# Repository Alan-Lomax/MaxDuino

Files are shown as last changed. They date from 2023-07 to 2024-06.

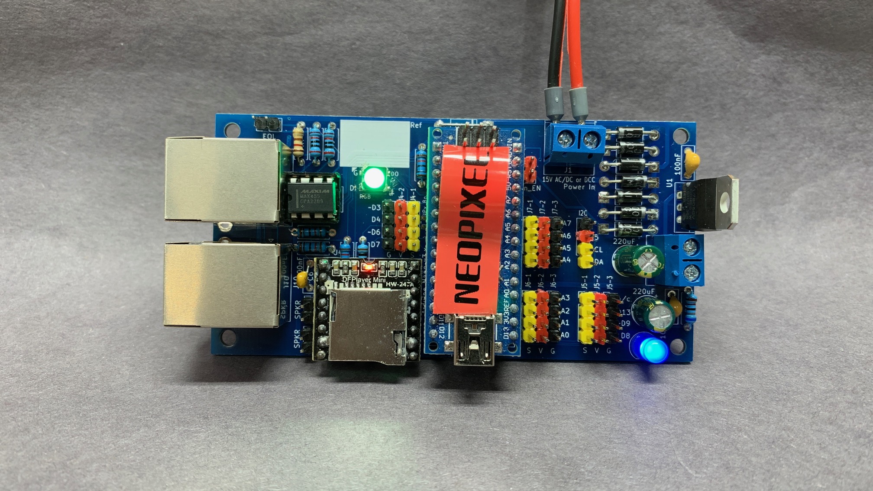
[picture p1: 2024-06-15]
R1.6 (With RJ45)/Images/MaxDuino_R1.5_Under_Test.jpg

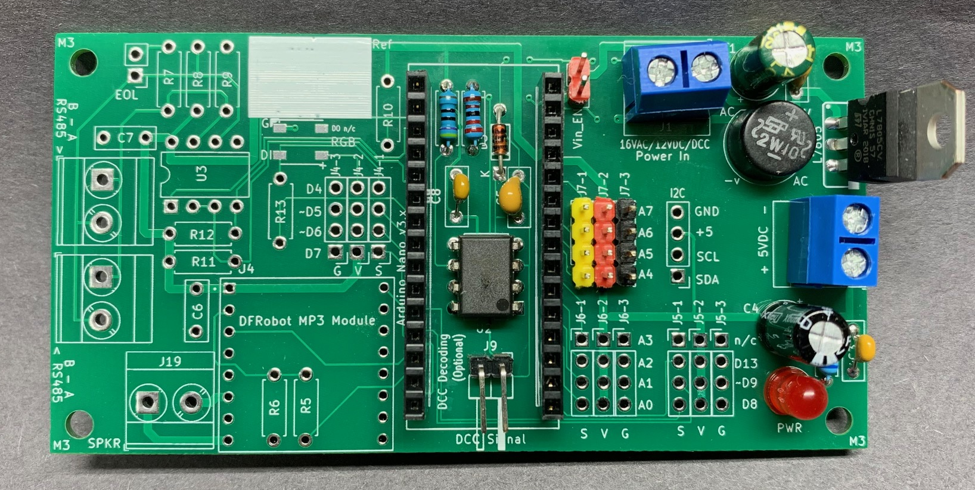
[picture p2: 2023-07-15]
MaxDuino Resources/Construction Photos/07 MaxDuino Header Pins Partially Installed.png

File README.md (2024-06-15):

# MaxDuino
Is a small PCB carrier board that acts as a host for an Arduino NANO.
The PCB provides a multitude of supporting features for the NANO.
It is targeted for use as a model railway animation tool (see feature list)
Because of its flexibility it can be used in many different scenarios.

<B>There are two current versions according to needs:</B>
<Li>R1.6 uses RJ-45 jacks (network patch cords) for power and communications
<Li>R1.4 uses screw terminals for simple wire connections

## Key Features
<Li>Arduino Nano R3 is fully utilized.
<Li>On board NeoPixel for flexible diagnostic use and status reporting.
<Li>Robust on board DC power supply (5V DC, 9-15V DC/AC, or DCC)
<Li>DFRobot MP3 player with SD card and speaker terminals
<Li>Lots of 3 pin headers and an I2C header
<Li>Opto Isolator for decoding DCC packets
<Li>A RJ45 jack is used to connect 12VDC power and RS485 signals between R1.6 boards
<li>Two sets of jacks are provided for easy daisy chaining
<Li>The MAX485 chip has seperate DE/RE pins allowing ICSP of the Arduino. 
<Li>Sample sketches for testing, and to accelerate your own development.
<Li>Detailed build instructions are provided in Excel.

## Status of MaxDuino development 
### Rev 1.6 Is The Latest RJ45 Version 
<Li>No functionality differences vs R1.5.  Minor improvements are: 
<Li>Improved spacing around votage regulator for heatsink mounting
<Li>Added stencilling around 5 volt terminals indicating polarity
<Li>Brought the preamp pins on the Mp3 player out to pads (some people uae external amps)

Since the R1.4 version
<Li>The previous screw terminals for RS485 have been replaced with RJ45 jacks.
<Li>The power supply section received a major redesign.
<li>The round bridge diode is replaced with 4 discrete diodes.
<Li>3 additional diodes are used to drop the input voltage into the L7805 regulator
<Li>A diode has been used to prevent backfeeding power onto the network cable 
(Substitute a jumper where feeding power out is the desired behaviour)
<li>Screw terminals for a speaker are deleted. (Now using 2 pin headers)
<Li>Remote power and RS485 coms tested via a standard network patch cable</Li>
<Li><B>The full test suite has been run and all testing passed successfully.</B>

## Known Issues
<Li>None

### Rev 1.4 Is The Latest Version using screw terminals
<Li>This version is electrically the same as Version 1.3) however the 
<Li>silkscreen errors have been addressed</Li>
<Li><B>All functional testing passed successfully.</B></Li>
<Li>Updated test sketches provided. Test code reflects correct pin assignments,
<Li>Sketches are simplified and compartmentalized as to their the test scope.

### Rev 1.3 and Older Have been removed from GitHub (Files are in the archive)

## MaxDuino KiCad files including GERBERS.
The KiCad files are essentially 'source code' and include:
<Li>the schematic and
<Li>the Printed Circuit Board art work
The Kicad software checks for consistency between these two.

The Gerber files can be thought of as the 'compiled version'. The Gerbers
are seperate files, one for each step in the manufacturing process of a PCB.
The Gerbers are normally saved as a ZIP file and the Zip file is what gets
submitted for manufacture at the fabrication facility of your choice.

# The Panel Version
The MaxDuino PCB is sized 50 mm x 100 mm which means it can easily be panelized
in sets of two. This makes the panelized Maxduino fit on a single 100 mm x 100 mm 
PCB which is the normal 'minimum size' for billing. The short version of this 
is you get twice as many MaxDuinos at no extra cost.

There is a seperate folder containing the Panelized version of the Gerbers.

# Be Aware
Normally all EDITS should be done to the 'single PCB' and then it be repanelized
To repanelize you start a new Kicad project (one with no contents)
and run a 'plug in' to panelize things. You will specfiy which other 
file has the PCB layout you want to panelize. You also set the number of
rows (2) and collumns (1)
The only manual step needed is to add a horizontal line on the edge cut layer.
This will be a 'Vee-Cut' and allows separating the two PCBs easily.

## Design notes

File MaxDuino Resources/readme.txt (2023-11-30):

These are notes and generally useful stuff relevant to the MaxDuino
This material is not essential in order to just build or use the MaxDuino

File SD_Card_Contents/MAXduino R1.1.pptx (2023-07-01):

## MAXduino R1.1

## MaxDuino Block Diagram

DC In (9-15VDC)

AC In (9-16VAC)

DCC In (9-16VAC)

Power Supply

Filtered DC

Regulated 5 VDC

5 VDC

Arduino NANO

5 VDC in or out

Vin_En

Speaker Terminals

MP3 Module

Two Sets
Terminals

RS-485

EOL_En

I2C Header

5 VDC

D10
D11
D12

Vin

D3

5 VDC

5 VDC

D0
D1
D2

A4
A5

D4

DCC Opto-Isolator

5 VDC

DCC Injection

5 VDC

NeoPixel

5 VDC

I/O Header Pins

D4, D5, D6, D7
D8, D9, D13
A0,A1,A2,A3
A4,A5,A6,A7

Only Aref and Reset pins are not used

## MAXduino R1.1

WS2812B
RGB Neopixel

Opto-Isolated DCC Decoding
Under Arduino Nano

16 VAC input or 12 VDC input or
DCC Input

RS485 and Terminals

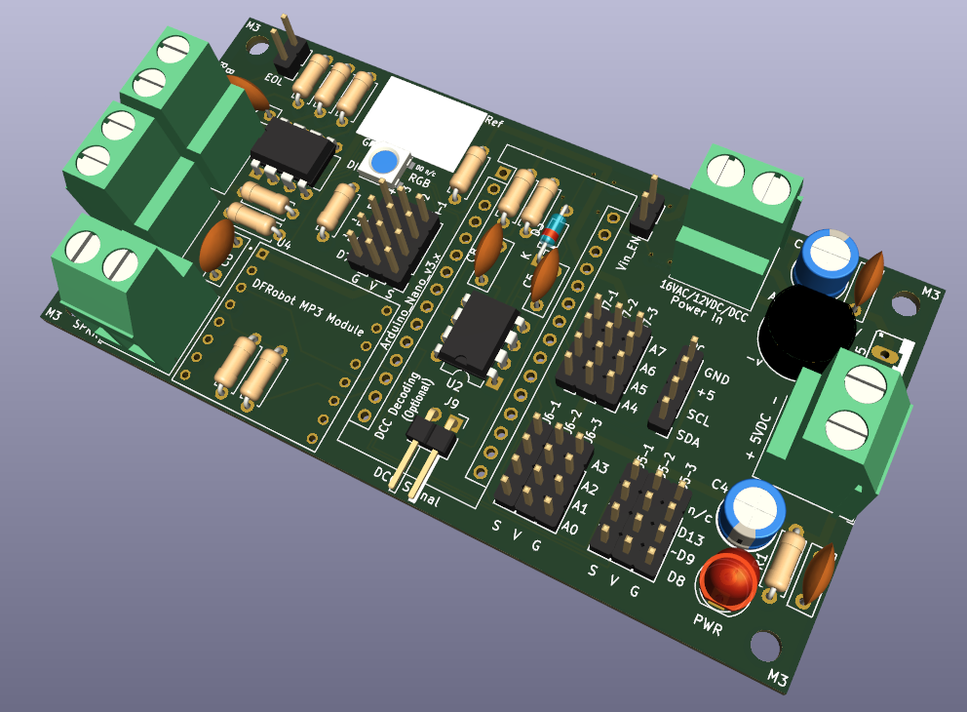
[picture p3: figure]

Versatile Power Supply

I2C

5 VDC input (or output)

Speaker Terminals

MP3 Player

I/O 3 pin headers in groups of 4

Power LED

## Design Review - Power Supply

Power comes in from the left. Up to 16VAC, 12VDC, or a DCC feed. It then goes through full wave bridge rectifier D1 and filter capacitors C1 and C2. This filtered DC voltage is now the input to the 5 volt regulator chip L7805.
The 5 volt regulator is capable of providing 1.5 amps and is internally protected against short circuits.
The 5 volt output is filtered with C3 and C4 to produce a rock steady 5 volt supply for significant projects.
A LED is used to indicate the presence of 5 volts (even without any Arduino present.)
On the right hand side is a second set of terminals which can be used as a 5 volt output to supply other circuits, or this can be used as a 5 volt input (in which case the L7805 regulator and everything to the left of it is not required.
On the left hand inputs, if DCC is used as the power source these signals are also routed to the DCC optoisolator circuit. Notes: The same voltage at the input to the voltage regulator chip can be routed to the Vin pin of the Arduino by inserting a jumper at J2. This is effectively puts the Arduinos own 5 volt regulator in parallel with the L7805. (You must verify Vin is 12VDC or less or the Arduinos on board regulator could be damaged).

## Design Review – DCC Decoder

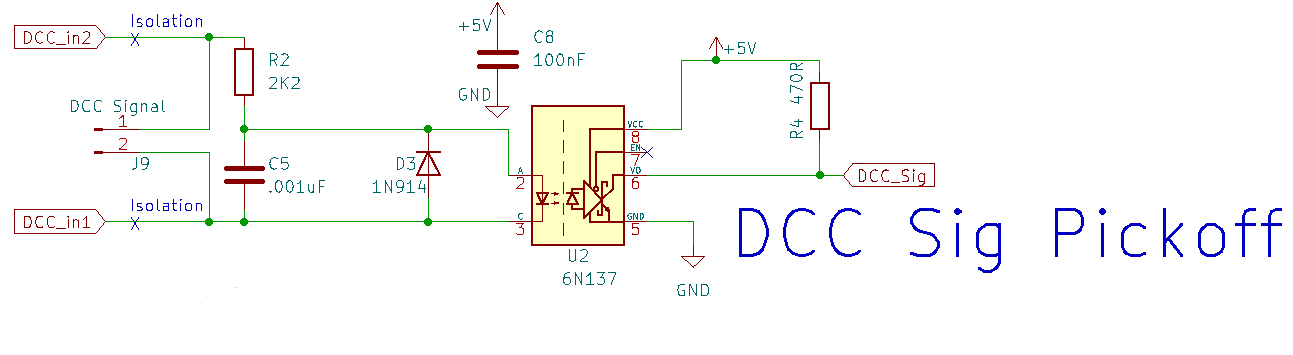
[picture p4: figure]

The DCC signal from the power circuit comes in on the left as DCC_in1 and DCC_in2. These are routed through two isolation points (thin traces on the PCB that can be scratched open circuit if needed). The DCC signal goes onto the 2K2 current limiting resistor R2 and then through the optoisolator U2. D3 provides reverse polarity protection for the optoisolator diode. C5 (in conjunction with R2) provide transient noise rejection. The output of the optoisolator goes to Arduino an pin and is pulled high by R4. Pin 7 is not used (The optoisolator is always enabled)
Note: Those components should be amongst the first installed for access reasons as the Arduino header pins will restrict access after those are installed.
NOTES: If DCC is not used as the MAXduino power supply but you still want to decode dcc signals then the two DCC isolation traces must be made open circuit. These traces are clearly marked on the bottom of the MAXduino PCB.
Once these traces are opened then any power source can be used for the board and an independent DCC signal for decoding can be input via J9 which is a pair of horizontal pins located on the PCB under the Arduino.

## Design Review – MP3 Player

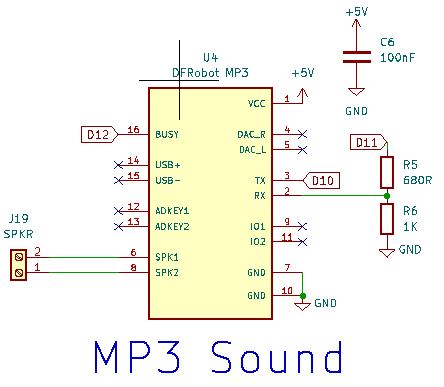
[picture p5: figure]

This circuit utilizes the common DFRobot MP3 player module. This module has an SD card reader and so it can play MP3’s located on a memory card. These can be sound effects, station announcements, or any other sounds as required.
Any small 8ohm speaker can be connected to the speaker terminals. To avoid speaker damage the speaker should be rated at 3 watts or more.
The Tx pin from the module connects to D10 on the Arduino while the Rx pin is connected to D11. The use of software serial is required to implement this but as the transmission speed is a relatively slow 9600 bps this is not an issue. A pair of resistors are used to lower the voltage received by this module as it can glitch if the receive voltage is even slightly over its 5 volt limit.

The busy pin is taken back to the Arduino on pin D12 to provide real time status information.
The following library has been tested #include <DFPlayerMini_Fast.h>
Note: The DFRobot MP3 player module is recommended. There is a similar module with part number MP3-TF-16P but it did not work well for me. Specifically It did not respond to some commands. (e.g.: setting volume)

## Design Review – RS-485 Communications

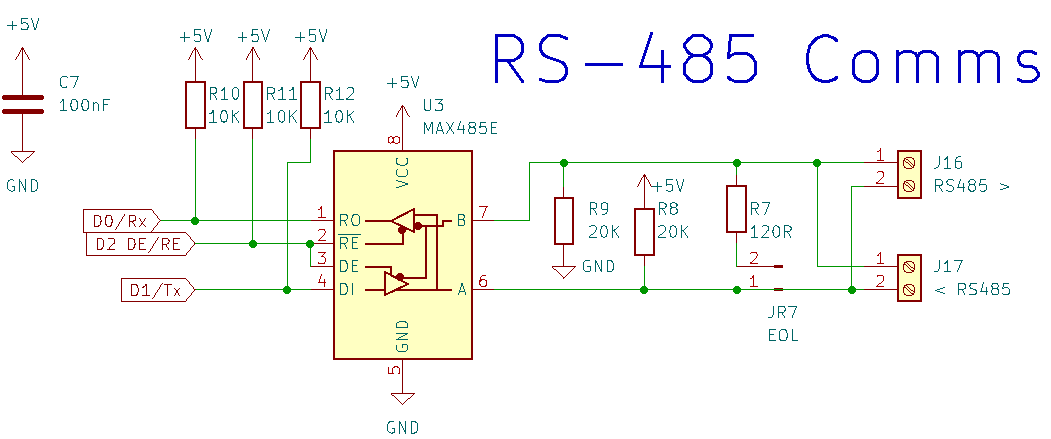
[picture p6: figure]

This circuit utilizes the common MAX485 chip to receive RS485 communications coming in from the right and convert them into standard logic level signals that the Arduino can read. There are two sets of terminals in parallel for the RS485 signals since this module is typically one ‘drop’ and the RS485 signals will daisy chain on. R7 is an EOL (End of Line) termination resistor. The jumper at JR7 should only be installed on one of the MAXduino boards and preferably the one farthest from the sending device (Typically a USB/RS485 interface). This chip interfaces with the Arduino Tx/Rx pins to take advantage of the Arduino UART. D2 sets the direction of transmission since RS485 is only half duplex (cannot transmit and receive at the same time).
The following libraries were used in testing
#include <Auto485.h>

#include <CMRI.h>

## Design Review – RGB

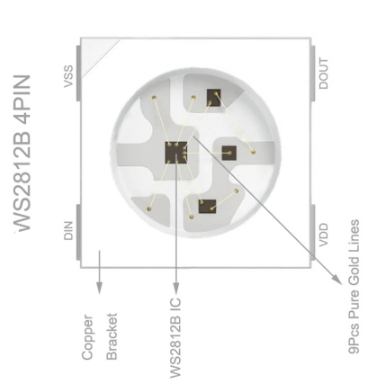
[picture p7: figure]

Pinout for WS2812B NeoPixel chip.
Note Vss = Ground. VDD = + 5 volts
The shown orientation matches the PCB

GND

DO (not used)

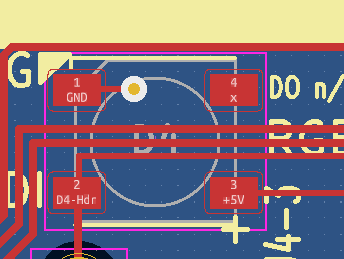
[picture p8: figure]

DI

+5 Volts

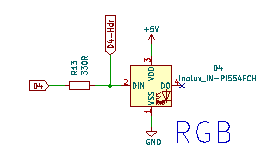
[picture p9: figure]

This small circuit utilizes the common addressable LED WS2812B NeoPixel chip to provide a wide range of colour feedback options. The circuit utilizes one Arduino pin (D4) and has an on board 330 ohm (alternate=470) series resistor for the input pin. The three pin header with D4 is also available and suitable for longer strings of NeoPixel addressable LED’s. Be sure to consider power requirements when using long (more than 30 elements) strings of NeoPixels. Note the PCB stencil has been improved to include chip placement details.
The following library was used in testing
#include <FastLED.h>

## Design Review – Header Pins

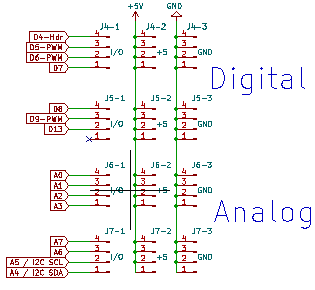
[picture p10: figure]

The I/O pins are arranged as four groups of four.
On the PCB this enables colour coded pins in strips of 4 to be used.
Each of the 15 I/O pins (one is not used) is presented as a 3 pin header.
The pin order is Signal, +5V, Ground … or S V G for short.
This pin order is a common but not universal (so always check your modules)
On the PCB some pins are marked with a tilde ( ~ ).
This is indicating these pins are PWM enabled.
Note A4/A5 pins are also part of the I2C header.

The I2C header provides +5, Ground, SCL and SDA
In the same order as commonly found on OLED displays. Be sure to check the pin order for each device when using I2C. You may of course elect to install these as colour coded pins.

## Design Review – Arduino

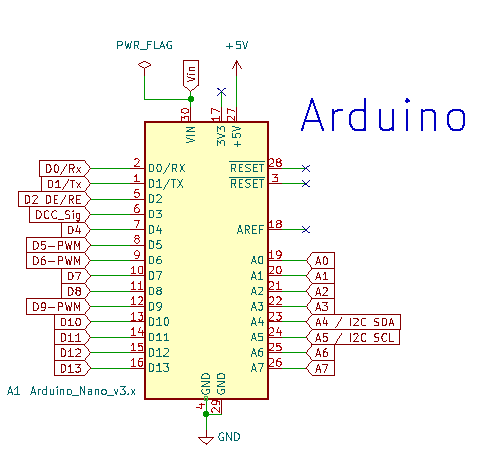
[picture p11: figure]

The Arduino NANO module is almost fully utilized as shown. Only 4 pins have no connections to them.
It is recommended to install female header pins on the PCB so that the NANO module can be simply plugged into those header pins. This also provides ample clearance for the DCC decoder circuit which is located under the Arduino.

## Design Review Full Schematic

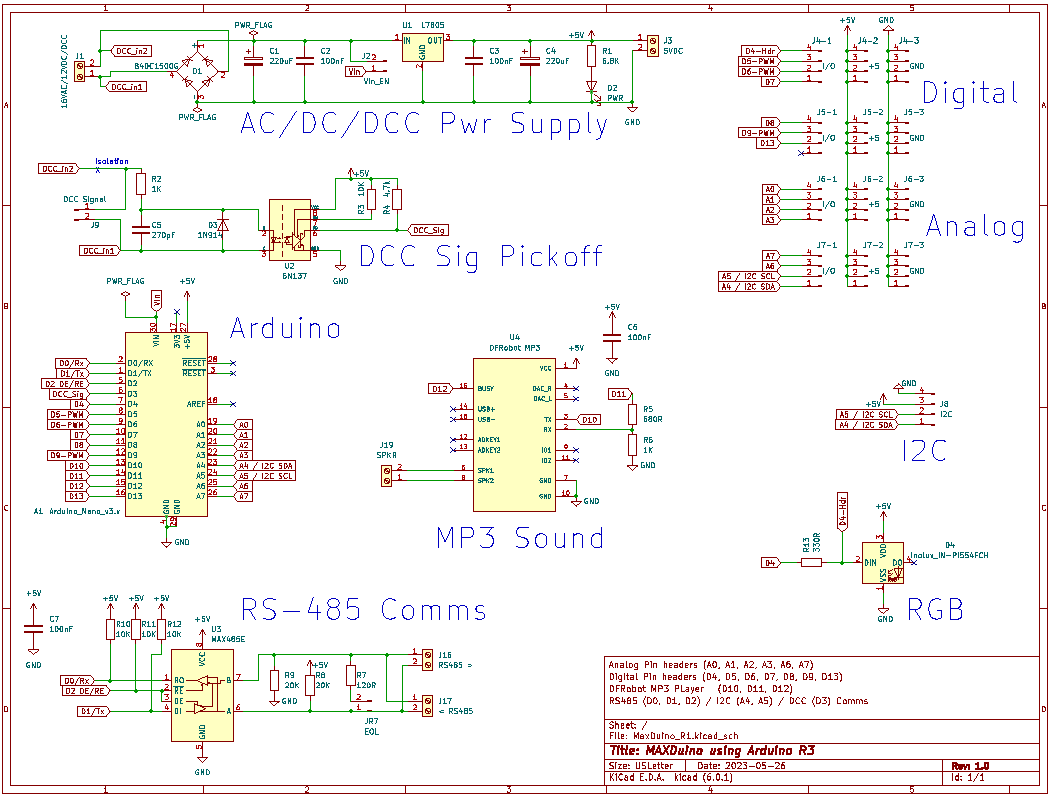
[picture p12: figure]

## Design Review Full PCB

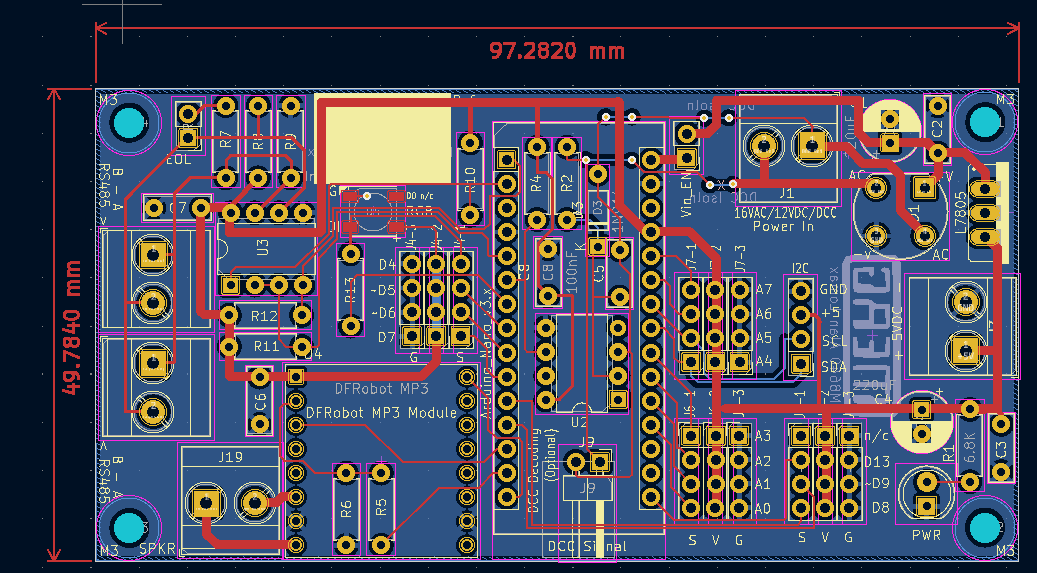
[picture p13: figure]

## Management of Change

Rev 0 – Dec 2022 first 10 prototypes ordered. Built up and tested.
Rev 1 – May 29 2023 second batch of 10 prototypes ordered. Fixed DCC decoding, added 5 volt power input, added NeoPixel, changed 3 pin header and I2C header arrangement, Larger power traces, clarified stenciling. Rev 1 arrived June 12 2023: 3 of 5 boards (they contacted me about 2 that failed manufacturing) – credit note is on file but 3 is enough for testing.
One PCB (Two MaxDuino) were given to Ian for evaluation.
Rev 1.1 Revised DCC Decoder circuit. Additional stencil near RGB NeoPixel to aid with orientation, additional stencil for double isolation of DCC signal pickoff from power supply section.
Ordered 5 PCB’s June 29 2023 from JLCPCB.

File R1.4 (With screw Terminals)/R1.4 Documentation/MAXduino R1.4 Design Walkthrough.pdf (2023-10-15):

# MaxDuino R1.4 Design Walkthrough

Note: In some cases photos of a previous revision are used where there is no material difference to the main message.

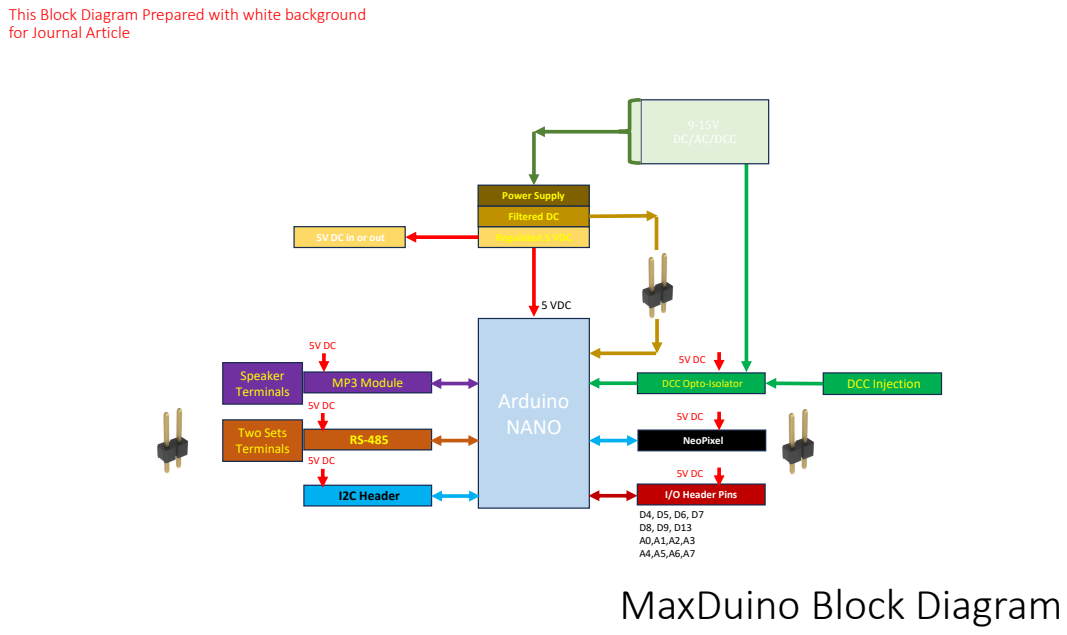
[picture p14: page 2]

This Block Diagram Prepared with white background
for Journal Article

5V DC in or out

# MaxDuino PCB

## (General arrangement)

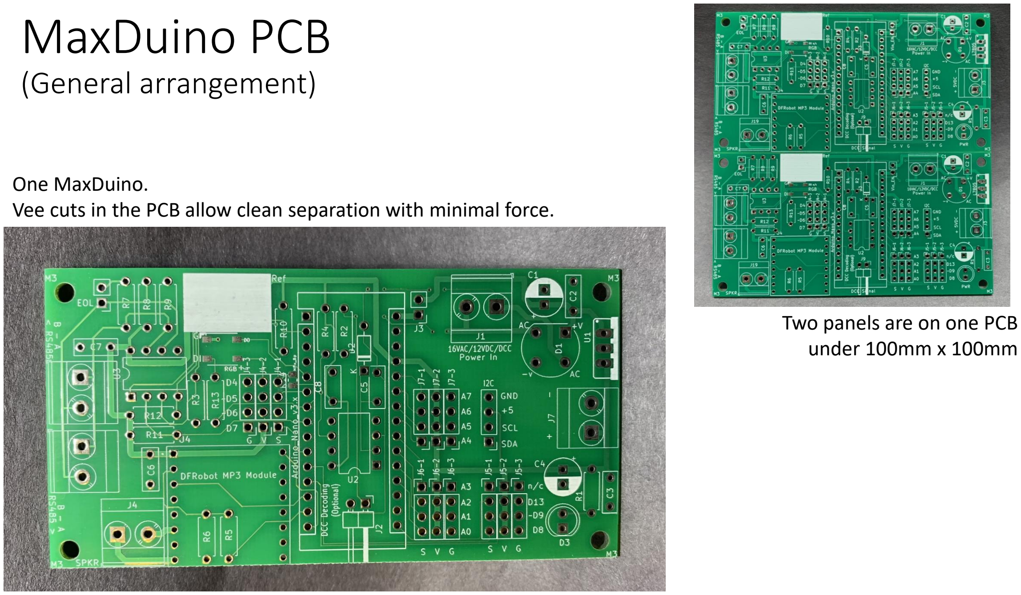
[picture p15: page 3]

Two panels are on one PCB
under 100mm x 100mm

One MaxDuino.
Vee cuts in the PCB allow clean separation with minimal force.

# MaxDuino 1.x

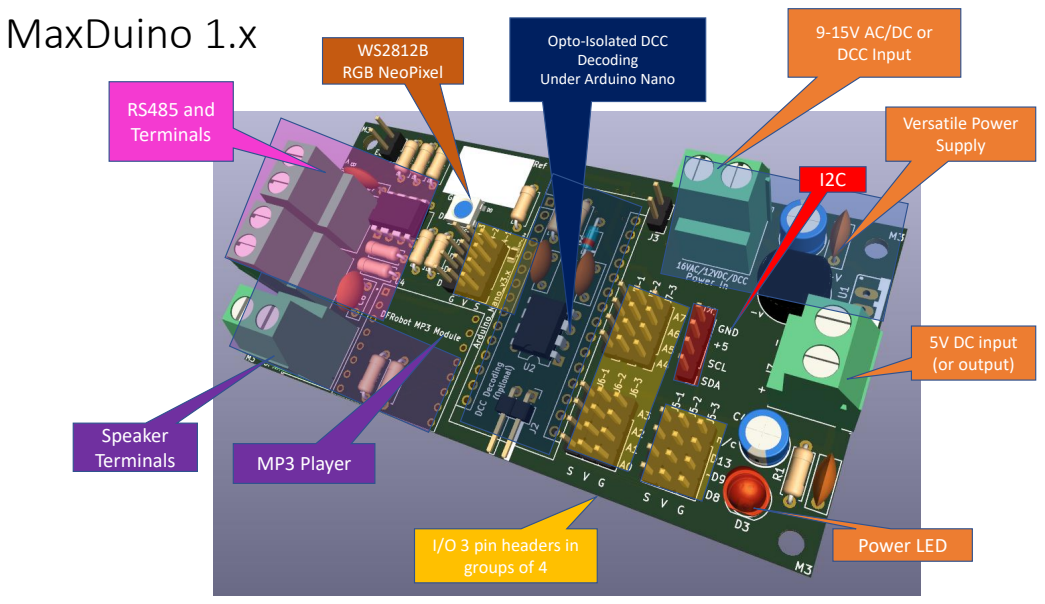
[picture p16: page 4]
Versatile Power Supply; 5V DC input (or output); MP3 Player; RS485 and Terminals; Power LED; WS2812B RGB NeoPixel; Speaker Terminals

DCC Input

Opto-Isolated DCC
Decoding
Under Arduino Nano

I/O 3 pin headers in
groups of 4

# Design Review - Power Supply

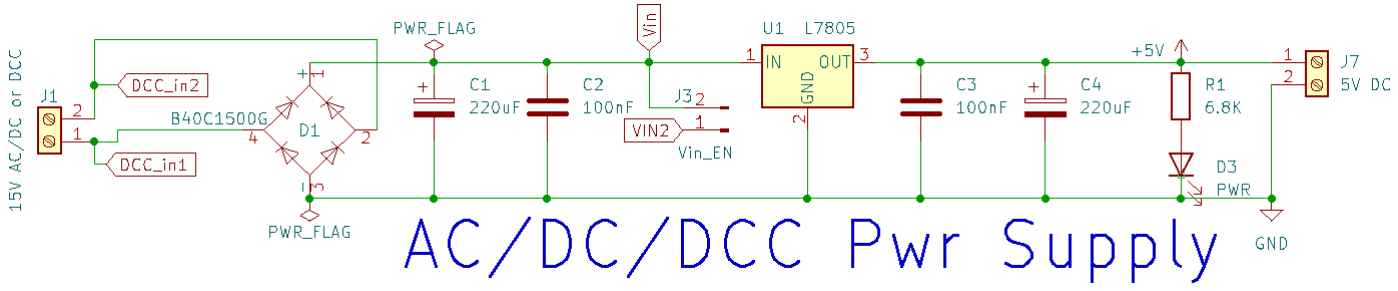
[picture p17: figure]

Power comes in from the left. Up to 9-15V AC/DC, or a DCC feed. It then goes through full wave bridge rectifier D1 and filter capacitors C1 and C2. This filtered DC voltage is now the input to the 5 volt regulator chip L7805.
The 5 volt regulator is capable of providing 1.5 amps and is internally protected against thermal overloads and short circuits. The 5 volt output is filtered with C3 and C4 to produce a steady 5 volt supply for significant projects. These capacitors are also needed to ensure stability of the voltage regulator. A LED is used to indicate the presence of 5 volts (even without any Arduino present.) On the right hand side is a second set of terminals which can be used as a 5 volt output to supply other circuits, or this can be used as a 5 volt input (in which case the L7805 regulator and everything to the left of it is not required.
Notes: If DCC is used as a power source the use of a heat sink on the L7805 is strongly recommended. Also if DCC is used as the power source that signal is also routed to the DCC optoisolator circuit.
The input to the voltage regulator chip Vin can be routed to the Vin pin of the Arduino by inserting a jumper at Vin_En. This puts the Arduinos own 5 volt regulator in parallel with the L7805. (You must verify Vin is 12VDC or less else the Arduinos on board regulator could be damaged).

# Design Review – DCC Decoder

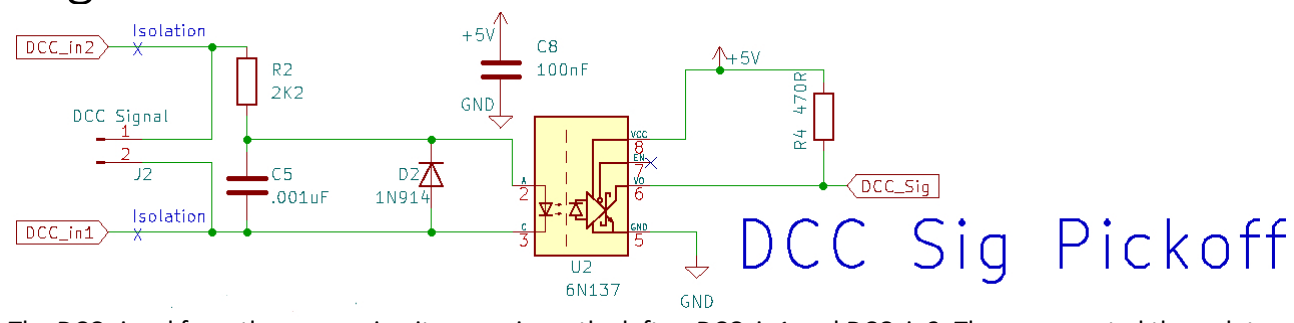
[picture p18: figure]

The DCC signal from the power circuit comes in on the left as DCC_in1 and DCC_in2. These are routed through two isolation points which are thin traces and are clearly marked on the bottom of the MaxDuino PCB.
The DCC signal goes onto the 2K2 current limiting resistor R2 and then through the optoisolator U2. D2 provides reverse polarity protection for the optoisolator diode. C5 (in conjunction with R2) provide transient noise rejection. Pin 7 is not used as the optoisolator has an internal pulllup. The output of the optoisolator goes to Arduino an pin and is pulled high by R4. Note the DCC input goes to Arduino Pin D3. This is very important because this is only one of two pins on the Nano that can have interrupts attached which is important for time critical decoding.

NOTES: If DCC is not used as the MaxDuino power supply but you still want to decode dcc signals then the two DCC isolation traces must be made open circuit. Once these traces are opened then the MaxDuino power source and the DCC decoding are isolated from each other. An independent DCC signal for decoding can be input via J2 which is a pair of horizontal pins located on the PCB under the Arduino.

# Design Review – MP3 Player

This circuit utilizes the common DFRobot MP3 player module. This module has an SD card reader and so it can play MP3’s located on a memory card. These can be sound effects, station announcements, or any other sounds as required.
Any small 8ohm speaker can be connected to the speaker terminals. To avoid speaker damage the speaker should be rated at 3 watts or more.

The Tx pin from this module connects to D10 on the Arduino while the Rx pin is connected to D11. The use of software serial is required to implement this but as the transmission speed is a relatively slow 9600 bps this is not an issue. A pair of resistors are used to lower the voltage received by this module as it can glitch if the Rx voltage is even slightly over its 5 volt limit.
(Alternate design – omit R6, use 1K resistor for R5)

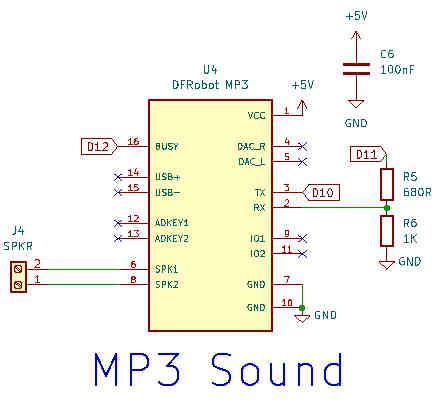
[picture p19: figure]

The busy pin is taken back to the Arduino on pin D12 to provide real time status information.
It is possible to ‘ask’ the module for its status via software also. Both approaches have been tested and work as expected. The following library has been tested #include <DFPlayerMini_Fast.h>

Note: The DFRobot MP3 player module is recommended. There is a similar module with part number MP3-TF-16P but it did not work well for me. Specifically It did not respond to some serial commands. (e.g.: setting volume)

# Design Review

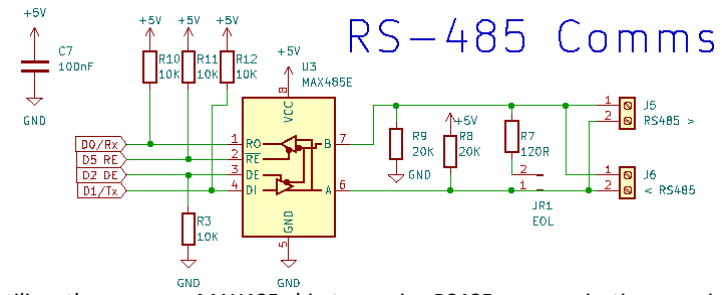
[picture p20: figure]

This circuit utilizes the common MAX485 chip to receive RS485 communications coming in from the right and convert them into standard logic level signals that the Arduino can read. There are two sets of terminals in parallel for the RS485 signals since this module is typically just one ‘drop’ and the RS485 signals will daisy chain onward. R7 is an EOL (End of Line) termination resistor. The EOL jumper at R7 should only be installed on one of the MaxDuino boards and preferably the one farthest from the sending device (Typically a USB/RS485 interface). This chip interfaces with the Arduino Tx/Rx pins to take advantage of the Arduino UART. As of R1.3 both D2 and D5 set the direction of transmission. The use of pull up and pull down resistors on these means that in circuit serial programming can work without disrupting other RS485 communications on the wires. (In the instance of a large network for example).
The following libraries were used in testing
#include <Auto485.h>

#include <CMRI.h>

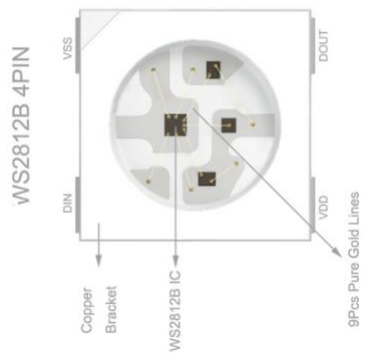
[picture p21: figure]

# Design Review – NeoPixel

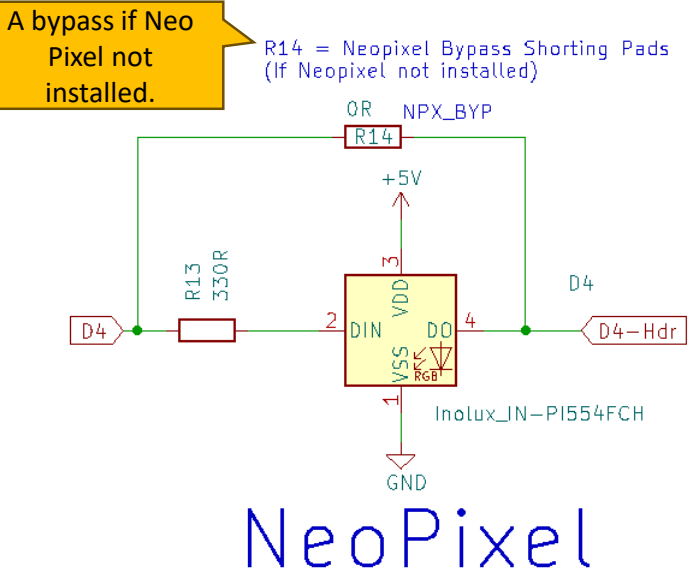
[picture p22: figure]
A bypass if Neo Pixel not installed.
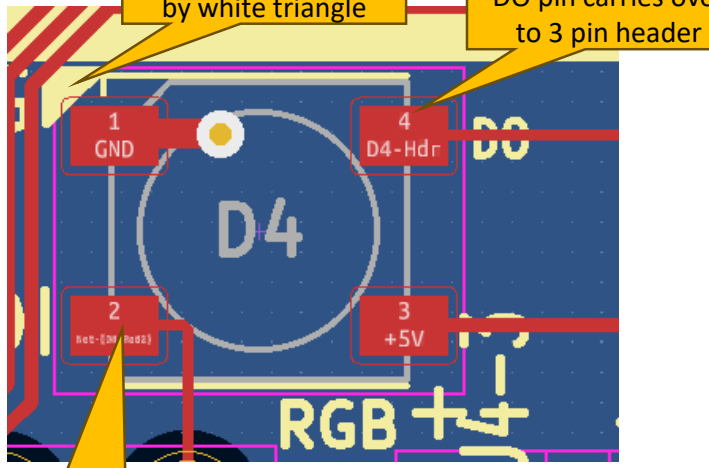
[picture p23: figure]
to 3 pin header

This small circuit utilizes the common addressable LED WS2812B NeoPixel chip to provide a wide range of colour feedback options. The circuit utilizes one Arduino pin (D4) and has an on board 330 ohm series resistor for the input pin. The three pin header with D4 is also available and suitable for longer strings of NeoPixel addressable LED’s. Be sure to consider power requirements when using long (more than 10 elements) strings of NeoPixels. Note a bypass set of pads exist (R14 is specified as a SMD component nut is not normally installed – only the solder pads are used and can shorted if the NeoPixel is not installed. Doing so connects D4 directly to the header pin bypassing the onboard Neo Pixel. If the header pin D4 is used for additional NeoPixels the onboard NeoPixel is index 0, and the external NeoPixels start at index 1. The following library was used in testing #include <FastLED.h>.

Pinout for WS2812B NeoPixel chip. Note Vss = Ground. VDD = + 5V
The orientation shown matches the PCB

Ground pin denoted
by white triangle | DO pin carries over

DI pin from NANO
pin D4 via 330R

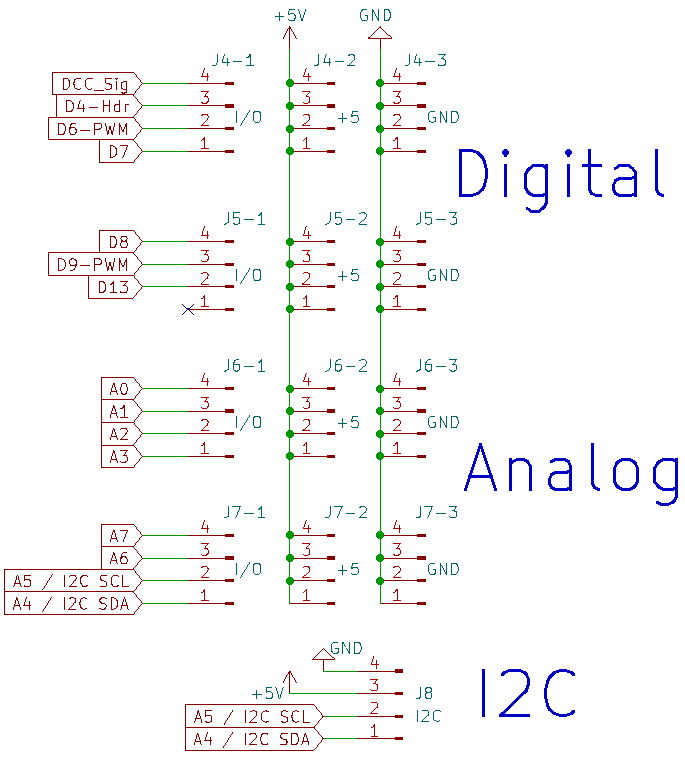
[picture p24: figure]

# Design Review – Header Pins

The I/O pins are arranged as four groups of four. Spaced to enables colour coded pins in strips of 4. Each of the I/O pins is presented as a 3 pin header. The pin order is Signal, +5V, Ground or S V G for short. This pin order is a common but not universal (so always check your modules)

On the PCB some pins are marked with a tilde ( ~ ). This is indicating these pins are PWM enabled.

Notes: There are subtle differences in the arrangement of the header pins between PCB version 1.3 and 1.4 Version 1.4 is shown.

The DCC decoder circuit ties into pin D3. It has a strong (470 ohm) pullup located on the PCB. Pin D4 is normally the output of the on-board NeoPixel. A4/A5 pins are also part of the I2C header. The I2C header provides +5, Ground, SCL and SDA (In the same order as commonly found on OLED displays.) Be sure to check your pin order when using I2C.

# Design Review – Arduino

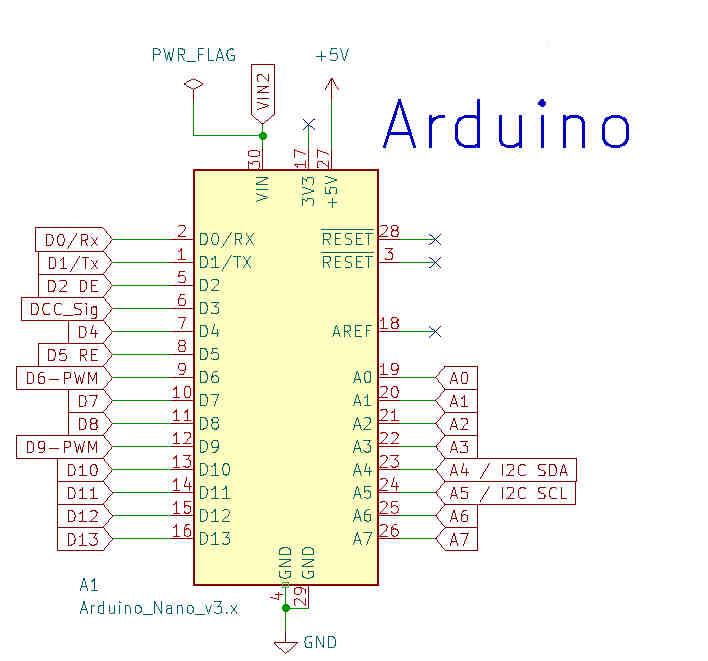
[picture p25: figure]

The Arduino NANO module is almost fully utilized as shown. Only 4 pins have no connections to them.

As of R1.3 both D2 and D5 are used for RS485 direction control.

It is recommended to install female header pins on the PCB so that the NANO module can be simply plugged into those header pins. This also provides ample clearance for the DCC decoder circuit located under the Arduino.

# Design Review Full Schematic

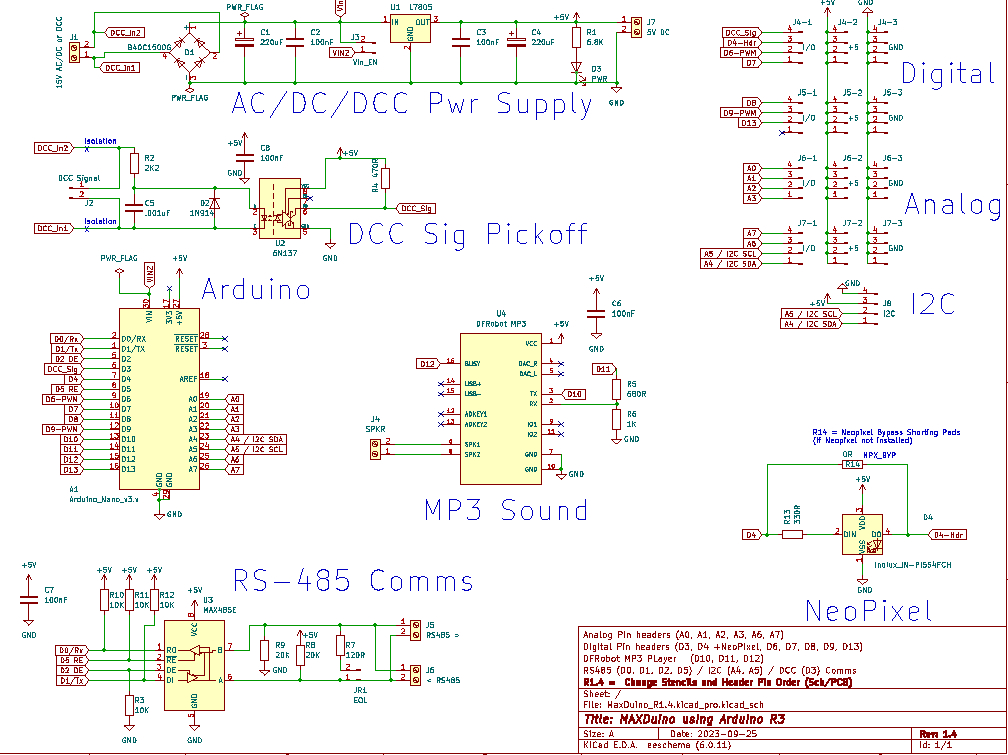
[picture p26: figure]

# Design Review Full PCB


# Management of Change

Rev 0 – Dec 2022 first 5 PCB’s (enough for 10 prototypes) ordered. Platform for developing test code.

Rev 1 – May 29 2023 second batch of 5 PCB’s ordered. Tried fixing DCC decoding, added 5 volt power input, added NeoPixel, changed 3 pin header and I2C header arrangement, Larger power traces, clarified stenciling. Found flaw in DCC Decoder section. One PCB (Two MaxDuino) were given to Ian for evaluation.

Rev 1.1 Revised DCC Decoder circuit. Additional stencil near RGB NeoPixel to aid with orientation, additional stencil for double isolation of DCC signal pickoff from power supply section.
Ordered two batches of 5 PCB’s June 29 2023 from JLCPCB. All testing passed.

Rev 1.2 Revised RS485 circuit to use 2 pins for enabling direction control. This puts both into high impedance state when doing ICSP. Also added flow through for the on board NeoPixel and ability to bypass the NeoPixel if not needed.

Rev 1.3 Previous revision changed the pin for DCC decoding – to one that does not support interrupts. This version moves DCC decoding back to pin D3 while retaining 2 pin direction control on RS485. All testing passed on October 14 2023.

Rev 1.4 During final prep of MERG article editor suggested minor changes that in turn suggested minor fixes to front and back stenciling. Circuit was electrically unchanged from version 1.3

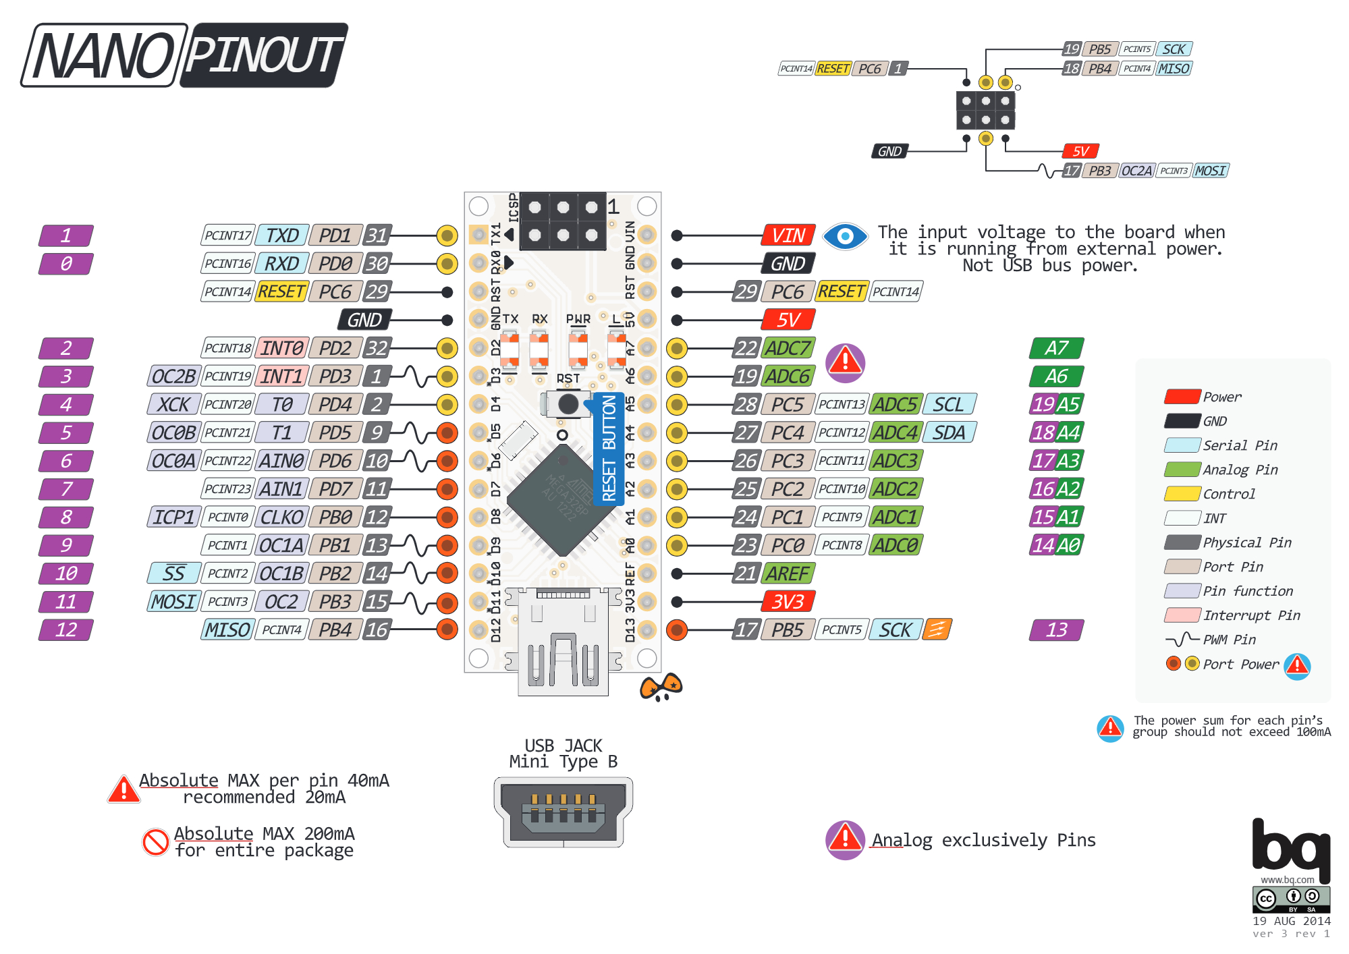
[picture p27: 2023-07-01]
MaxDuino Resources/DataSheets/NANO_PINOUT.jpg

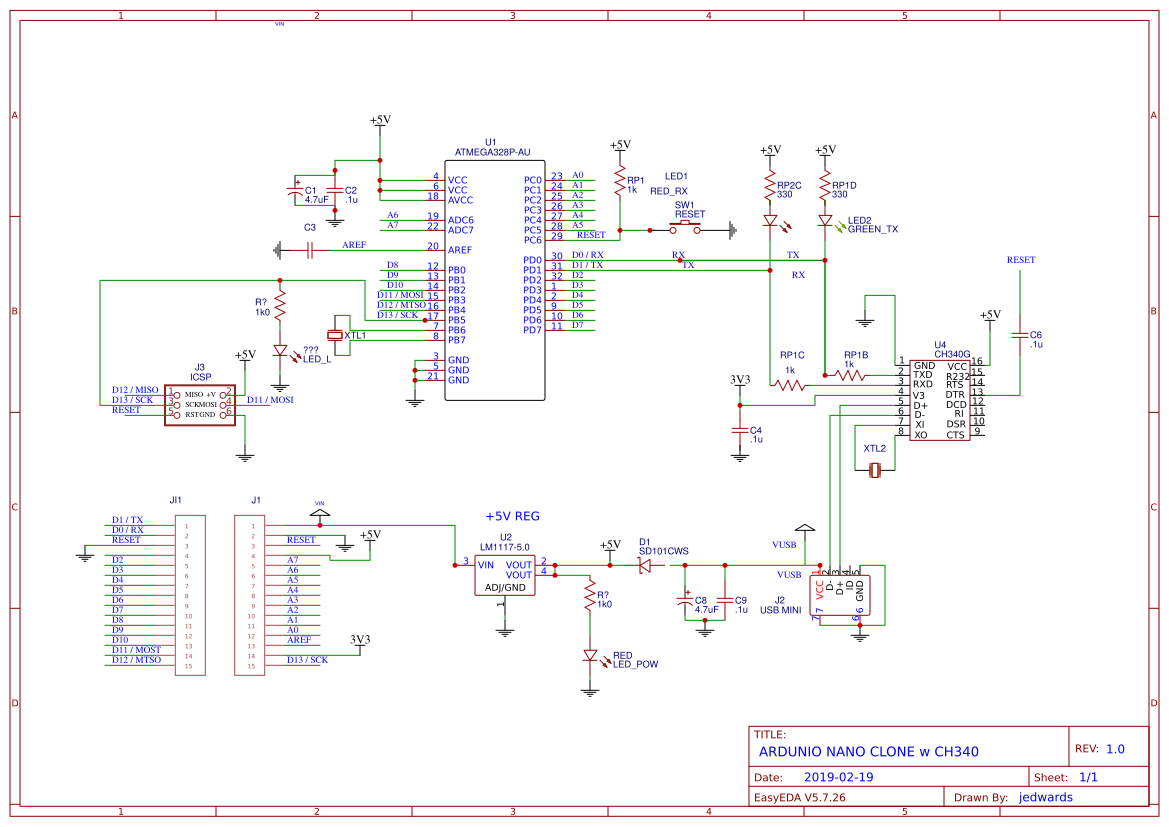
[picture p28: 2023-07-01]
MaxDuino Resources/DataSheets/Nano Schematic.png

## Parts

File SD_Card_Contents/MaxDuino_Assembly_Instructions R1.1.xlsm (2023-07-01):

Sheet: Instructions
 | MaxDuino Assembly Instructions R1.1
 | Known Issues | None. This document is draft and will be updated as needed.
Step | Action | Comments
 |  | With the MaxDuiono PCB there is some flexibility in which functions you wish to implement, and therefore what parts you need to include or not. (for example you may not wish to include the MP3 player module). To facilitate this a tab in this workbook is a configuration sheet that allows you to pick the features you want a given PCB to have. This then produces a consolidated parts list for just those features. The assembly instructions are broken down into sections (on the brown tabs below) according to the functions. So .. start with these 3 instructions:
1 | Make Choices | On the features tab chose the features you want on up to 5 different MaxDuino modules
2 | Review consolidated BOM | The consolidated BOM lists the parts you need to implement the features you have selected. There is a column where you can put your parts on hand I have included links for many of them. Note that in many cases you are buying in bulk (say 10 pieces where you may only need 2). Generally this is still more economical. Pricing is highly variable and was current as of June 2023. Shipping reflects my location (Canada) .. yours will of course be different.
3 | Wait for Parts | Organize your parts and workspace. You will need a soldering iron (pencil type preferred) and some acid free electronics solder. A small bead of 'bluetack' putty is very helpful but not strictly required. (to hold the components in place when you flip the circuit board over to solder that first lead in place.)
 | General advice | Before soldering use the Printed Circuit Board (PCB) as a guide and bend diode and resistor leads 90 degrees so they match the hole spacing on the PCB. In general it is a best practice is to start with the smaller parts closest to the surface of the PCB and work on up to the taller / larger parts. Solder only one component onto the board at a time AND also solder only one lead of that component. Flip the PCB over and verify proper orientation and fit to the board before resuming soldering the remaining leads and moving onto the next component. As parts are soldered into place the excess leads can be trimmed off the bottom using small cutters.

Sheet: Features
Home
 |  | Module #1 | Module #2 | Module #3 | Module #4 | Module #5
 | Arduino | 1 | 0 | 0 | 0 | 0 | Required per module
 | Flexible Power Supply | 1 | 0 | 0 | 0 | 0
 | 5 Volt Input Power Supply | 1 | 0 | 0 | 0 | 0
 | DCC Decoder | 1 | 0 | 0 | 0 | 0
 | MP3 Player | 1 | 0 | 0 | 0 | 0
 | RS485 communications | 1 | 0 | 0 | 0 | 0
 | I/O Headers | 1 | 0 | 0 | 0 | 0
 | I2C Headers | 1 | 0 | 0 | 0 | 0
 | RGB Neopixel | 1 | 0 | 0 | 0 | 0
Instructions:
1 | For each module indicate features you want the module to have by clicking the appropriate cell.
2 | Refer to Consolidated BOM for your parts / shopping list
Notes: | A flexible power supply requires 5 volt power supply parts also. (The 5 volt supply can work without the flexible supply)
 | A MaxDuino PCB is Implied per Module of course!
 | For current hardware test status see tab:
 | PCB R1 Testing

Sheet: Consolidated BOM
References | Value | Needed Count | On Hand | To Get | Supplier | Description | Link | Multiplier | Qty | Unit Price | Shipping | Extended Price (Needed Parts Only) | Extended Price (All Parts)
A1 | Arduino_Nano_v3.x (Check MaxDuino PCB also) | 1 | 0 | 1 | AliExpress | Atmega328P with Mini USB (Needs Soldering) | Link (https://www.aliexpress.com/item/1005002966043359.html) | 1 | 1 | $2.93 | $1.42 | $4.35 | $4.35
 | Female Header Pins for Arduino | 1 | 0 | 1 | AliExpress | 10 pieces 1x40 female header pin | Link (https://www.aliexpress.com/item/1005002577212594.html?curPageLogUid=OAFMO7EpaR5l) | 0.1 | 1 | $2.45 | $2.00 | $0.45 | $0.45
 | Female Header Pins for MP3 module | 1 | 0 | 1 | AliExpress | 10 pieces 1x40 female header pin | Link (https://www.aliexpress.com/item/1005002577212594.html?curPageLogUid=OAFMO7EpaR5l) | 0.1 | 1 | $2.45 | $2.00 | $0.45 | $0.45
C1,C4 | 220uF 25VDC | 2 | 0 | 2 | AliExpress | 20 pieces Electrolytic Capacitor | Link (https://www.aliexpress.com/item/1005004304037018.html?curPageLogUid=8TY8WNbrsxtg) | 0.05 | 2 | $1.03 | $2.53 | $0.36 | $0.36
C2, C3, C6, C7, C8 | 100nF (0.1uF) commonly marked as 104 | 5 | 0 | 5 | AliExpress | Qty 100 50V Ceramic | Link (https://www.aliexpress.com/item/1005002290441861.html) | 0.01 | 5 | $1.19 | $1.72 | $0.15 | $0.15
C5 | .001uF commonly marked as 102 | 1 | 0 | 1 | AliExpress | Qty 100 50V Ceramic | Link (https://www.aliexpress.com/item/1005002290441861.html) | 0.01 | 1 | $1.19 | $1.72 | $0.03 | $0.03
D1 | B40C1500G | 1 | 0 | 1 | AliExpress | 10 pack of 2 AMP Bridge Rectifier | Link (https://www.aliexpress.com/item/32861907980.html) | 0.1 | 1 | $1.73 | $1.61 | $0.33 | $0.33
D2 | PWR LED | 1 | 0 | 1 | AliExpress | Assorted LEDs | Link (https://www.aliexpress.com/item/1005003480981131.html) | 0.01 | 1 | $5.49 | $0.29 | $0.06 | $0.06
D3 | 1N914 | 1 | 0 | 1 | AliExpress | Qty 100 Fast Acting Signal Diode | Link (https://www.aliexpress.com/item/1005003345825307.html?curPageLogUid=WmEe9ymi5x88) | 0.01 | 1 | $1.52 | $1.56 | $0.03 | $0.03
D4 | Inolux_IN-PI554FCH | 1 | 0 | 1 | AliExpress | WS2812B Neopixel (White surface mount) | Link (https://www.aliexpress.com/item/4001345875756.html) | 0.1 | 1 | $1.24 | $0.00 | $0.12 | $0.12
J1, J3, J16, J17, J19 | Screw Terminals | 5 | 0 | 5 | AliExpress | 20 pack of Small screw Terminals for PCB | Link (https://www.aliexpress.com/item/1005004039299571.html) | 0.05 | 5 | $1.68 | $1.91 | $0.90 | $0.90
J2, JR7 | 2 pin male header | 2 | 0 | 2 | AliExpress | 10 pieces 40 pin header | Link (https://www.aliexpress.com/item/1005003016826921.html) | 0.005 | 2 | $0.86 | $1.43 | $0.02 | $0.02
J4-1, J5-1, J6-1, J7-1, J8 | 4 pin header Yellow | 5 | 0 | 5 | AliExpress | 10 pieces 40 pin header | Link (https://www.aliexpress.com/item/1005003016826921.html) | 0.01 | 5 | $0.86 | $1.43 | $0.11 | $0.11
J4-2, J5-2, J6-2, J7-2 | 4 pin header Red | 4 | 0 | 4 | AliExpress | 10 pieces 40 pin header | Link (https://www.aliexpress.com/item/1005003016826921.html) | 0.01 | 4 | $0.86 | $1.43 | $0.09 | $0.09
J4-3, J5-3, J6-3, J7-3 | 4 pin header Black | 4 | 0 | 4 | AliExpress | 10 pieces 40 pin header | Link (https://www.aliexpress.com/item/1005003016826921.html) | 0.01 | 4 | $0.86 | $1.43 | $0.09 | $0.09
J9 | 2 pin right angle male header | 1 | 0 | 1 | AliExpress | 10 pieces 40 pin right angle header | Link (https://www.aliexpress.com/item/4000694229610.html?curPageLogUid=bNZEWRNzBArE) | 0.01 | 1 | $1.23 | $1.61 | $0.03 | $0.03
R7 | 120R | 1 | 0 | 1 | AliExpress | Qty 100 1/4 watt 5% Resistor | Link (https://www.aliexpress.com/item/1005003818444423.html) | 0.01 | 1 | $0.64 | $1.35 | $0.02 | $0.02
R13 | 330R | 1 | 0 | 1 | AliExpress | Qty 100 1/4 watt 5% Resistor | Link (https://www.aliexpress.com/item/1005003818444423.html) | 0.01 | 1 | $0.64 | $1.35 | $0.02 | $0.02
R5 | 680R | 1 | 0 | 1 | AliExpress | Qty 100 1/4 watt 5% Resistor | Link (https://www.aliexpress.com/item/1005003818444423.html) | 0.01 | 1 | $0.64 | $1.35 | $0.02 | $0.02
R2, R6 | 1K | 2 | 0 | 2 | AliExpress | Qty 100 1/4 watt 5% Resistor | Link (https://www.aliexpress.com/item/1005003818444423.html) | 0.01 | 2 | $0.64 | $1.35 | $0.04 | $0.04
R4 | 470R | 1 | 0 | 1 | AliExpress | Qty 100 1/4 watt 5% Resistor | Link (https://www.aliexpress.com/item/1005003818444423.html) | 0.01 | 1 | $0.64 | $1.35 | $0.02 | $0.02
R1 | 6.8K | 1 | 0 | 1 | AliExpress | Qty 100 1/4 watt 5% Resistor | Link (https://www.aliexpress.com/item/1005003818444423.html) | 0.01 | 1 | $0.64 | $1.35 | $0.02 | $0.02
R10, R11, R12 | 10K | 3 | 0 | 3 | AliExpress | Qty 100 1/4 watt 5% Resistor | Link (https://www.aliexpress.com/item/1005003818444423.html) | 0.01 | 3 | $0.64 | $1.35 | $0.06 | $0.06
R8, R9 | 20K | 2 | 0 | 2 | AliExpress | Qty 100 1/4 watt 5% Resistor | Link (https://www.aliexpress.com/item/1005003818444423.html) | 0.01 | 2 | $0.64 | $1.35 | $0.04 | $0.04
U1 | L7805 T0220 | 1 | 0 | 1 | AliExpress | Qty 50 5 Volt Regulator | Link (https://www.aliexpress.com/item/1005005622160274.html?curPageLogUid=Y4rvTNfoPDhb) | 0.02 | 1 | $2.49 | $1.75 | $0.08 | $0.08
HeatSink | Optional T0220 Heatsink for U1 | 1 | 0 | 1 | AliExpress | Qty 10 heat sink with Mounting hardware | Link (https://www.aliexpress.com/item/4000190314199.html?scm_id=1007.40000.326746.0&scm-url=1007.40000.326746.0) | 0.1 | 1 | $1.16 | $2.42 | $0.36 | $0.36
U2 | 6N137 8 pin DIP | 1 | 0 | 1 | AliExpress | OptoIsolator | Link (https://www.aliexpress.com/item/1005002777275459.html?curPageLogUid=xG6J9gDGvLlx) | 0.1 | 1 | $2.24 | $1.56 | $0.38 | $0.38
U3 | MAX485E 8 pin DIP | 1 | 0 | 1 | AliExpress | 10 pack Transceiver Chip | Link (https://www.aliexpress.com/item/1005002848215276.html?curPageLogUid=bMryawO8OFpU) | 0.1 | 1 | $1.42 | $1.56 | $0.30 | $0.30
U4 | DFRobot MP3 | 1 | 0 | 1 | AliExpress | Qty 10 DFRobot MP3 Module | Link (https://www.aliexpress.com/item/1005004522532733.html) | 0.1 | 1 | $11.05 | $6.54 | $1.76 | $1.76
SPKR | 8 ohm 3 watt | 1 | 0 | 1 | AliExpress | 3 watt speaker | Link (https://www.aliexpress.com/item/1005005457205541.html?curPageLogUid=SK1ZYRLQax4i) | 0.5 | 1 | $0.90 | $4.99 | $2.95 | $2.95
SD Card | any capacity under 32 GB | 1 | 0 | 1 | AliExpress | Small Capacity SD Card (32GB MAX) | Link (https://www.amazon.ca/Lerdisk-Wholesale-Capacity-Produced-Authorized/dp/B09VYYZT5G?s=pc) | 1 | 1 | $2.00 | $3.00 | $5.00 | $5.00
PCB | MaxDuino Printed Circuit Board | 1 | 0 | 1 | JLCPCB | Min order is 5 PCBs (2 ccts per) | Link (https://jlcpcb.com/) | 0.1 | 1 | $5.00 | $10.00 | $1.50 | $1.50
 |  |  |  |  |  |  |  |  |  |  | Total | $20.13 | $20.13
 |  |  |  |  |  |  |  |  |  | Extras | Lump Sum | $0.00 | $0.00
 |  |  |  |  |  |  |  |  |  | Extras (as %) | 0% | $0.00 | $0.00
 |  |  |  |  |  |  |  |  |  |  | All in | $20.13 | $20.13

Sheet: BOM
Reference(s) | Value | Flexible Power Supply | 5 Volt Input Power Supply | DCC Decoder | MP3 Player | RS485 communications | I/O Headers | I2C Headers | RGB Neopixel | Arduino
A1 | Arduino_Nano_v3.x |  |  |  |  |  |  |  |  | 1
 | Female Header Pins for Arduino |  |  |  |  |  |  |  |  | 1
 | Female Header Pins for MP3 module |  |  |  | 1
C1 | 220uF | 1
C2 | 100nF | 1
C3 | 100nF |  | 1
C4 | 220uF |  | 1
C5 | .001uF |  |  | 1
C6 | 100nF |  |  |  | 1
C7 | 100nF |  |  |  |  | 1
C8 | 100nF |  |  | 1
D1 | B40C1500G | 1
D2 | PWR |  | 1
D3 | 1N914 |  |  | 1
D4 | Inolux_IN-PI554FCH |  |  |  |  |  |  |  | 1
J1 | 16VAC/12VDC/DCC | 1
J2 | Vin_EN 2 pin jumper | 1
J3 | 5VDC |  | 1
J4-1 | 4 pin header Yellow |  |  |  |  |  | 1
J4-2 | 4 pin header Red |  |  |  |  |  | 1
J4-3 | 4 pin header Black |  |  |  |  |  | 1
J5-1 | 4 pin header Yellow |  |  |  |  |  | 1
J5-2 | 4 pin header Red |  |  |  |  |  | 1
J5-3 | 4 pin header Black |  |  |  |  |  | 1
J6-1 | 4 pin header Yellow |  |  |  |  |  | 1
J6-2 | 4 pin header Red |  |  |  |  |  | 1
J6-3 | 4 pin header Black |  |  |  |  |  | 1
J7-1 | 4 pin header Yellow |  |  |  |  |  | 1
J7-2 | 4 pin header Red |  |  |  |  |  | 1
J7-3 | 4 pin header Black |  |  |  |  |  | 1
J8 | 4 pin header Yellow |  |  |  |  |  |  | 1
J9 | DCC Signal |  |  | 1
J16 | RS485 > |  |  |  |  | 1
J17 | < RS485 |  |  |  |  | 1
J19 | SPKR |  |  |  | 1
JR7 | EOL |  |  |  |  | 1
R1 | 6.8K |  | 1
R2 | 1K |  |  | 1
R3 | n/a since Rev 1.1
R4 | 470R |  |  | 1
R5 | 680R |  |  |  | 1
R6 | 1K |  |  |  | 1
R7 | 120R |  |  |  |  | 1
R8 | 20K |  |  |  |  | 1
R9 | 20K |  |  |  |  | 1
R10 | 10K |  |  |  |  | 1
R11 | 10K |  |  |  |  | 1
R12 | 10K |  |  |  |  | 1
R13 | 330R |  |  |  |  |  |  |  | 1
U1 | L7805 T0220 | 1
U2 | 6N137 8 pin DIP |  |  | 1
U3 | MAX485E 8 pin DIP |  |  |  |  | 1
U4 | DFRobot MP3 |  |  |  | 1
SPKR | 8 ohm 3 watt |  |  |  | 1
SD Card | any capacity |  |  |  | 1
 |  |  |  |  |  | `

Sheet: Power Supply
 | MaxDuino Assembly Instructions R1.1
 | Known Issues | None.
Step | Items | Action / Comments
Flexible Input Power Supply Section (optional only if providing your own external 5 VDC supply)
A1 | C1 (220 uFD) | Direction is important. Ensure the negative stripe matches the white half circle on the board. Note: Electrolytic Capacitors have voltage ratings in addition to their capacitance value. This capacitor should be rated for 25% more than your supply voltage. (ie if supply is 12 VDC this capacitor should be rated for at least 15 volts. If in doubt look for 25VDC ratings) | Figure 1
A2 | C2 (104) | Install and solder where indicated on PCB. Orientation is not important.
A3 | D1 (Bridge Rectifier) | Direction is Very Important. Ensure the Positive terminal is installed where +V is indicated.
A4 | U1 L7805 | Direction is important. The flat back must be towards the edge of the board. This voltage regulator chip does have thermal protection and will shut itself down if it gets too hot. For this circuit this should not happen unless there is a wiring mistake however for input voltages higher than 12 volts (including DCC) the use of a TO-220 heat sink is reccomended.
A5 | J1 | Screw terminals for connecting power onto the board
Regulated 5 Volt DC Power Supply Section
B1 | R1 (6.8K), C3 (104) | Install and solder where indicated on PCB. Orientation is not important.
B2 | C4 (220uFD) | Notes as per C1. Voltage rating not as important (10VDC or higher is fine)
B3 | D2 LED (5mm) | Direction is important. Note LED's have a flat molded into the plastic. Match it with the flat indicated on the PCB. As an additional check the side with the flat should have a shorter lead than the other one.
B4 | J2 | J2 is a two pin header to optionally route the DC power to Vin. If jumper is not installed on this header the Arduino Vin pin will not be used. (5 VDC from the L7805 regulator or an external 5 volt supply will power the Arduino instead)
B5 | J3 | Screw terminals to either supply 5VDC to board or take 5VDC from board.
Step | TEST | Observation
T1 | Visual | A quick visual check verifying component placement and no solder splatter. (For ideas of what to look for review the photos tab of this workbook)
T2 | Basic Power on 5 Volt checks | Apply your input power according to your build options. For the flexible input power option apply 12 VDC (or Low voltage AC or DCC) power to the main power input terminals. Note - all of these options go through a bridge rectifier diode so the polarity of the wires on the screw terminals is not important For the 5 volts only option connect your regulated 5 volt supply to the 5 volt input terminals. Do not ever connect both of the above power supplies at the same time. LED should light steady. Use finger to touch the back of the 7805. It should remain cool to the touch. Use a multimeter on a DC voltage scale. The screw terminals on the 5 volt connection point are a convenient place to check voltage. Also with the rows of empty S V G holes (for future header pins) it is easy to check for voltage by touching the negative multimeter lead to a G hole and the positive lead to a V hole (they dont need to be part of the same three hole set). The meter should read very close to 5 volts. In my test for example it was 5.03 volts
T3 | Remove Power | When you remove the input power (ideally switch your power supply off) the LED should fade off and not just suddenly go off. This indicates the capacitors are working properly.
T4 | Disconnect Power Leads to PCB | If all tests have passed then proceed to the next section.
Figure 1:

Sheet: DCC Decoder and Arduino
 | MaxDuino Assembly Instructions R1.1
 | Known Issues | None.
Step | Action | Comments
Opto-Isolated DCC Signal pickoff to Arduino (optional)
C1 | C5 (.001uF) (Marked 102) C8 (0.1uF) (Marked 104) | Because most of these components are phyiscally under the Arduino it is most convenient to install them before the arduino header pins are installed. Install and solder C5 and C8 where indicated on PCB. Orientation is not important. | Figure 2
C2 | R2 (2K2), R4 (470R) | Install and solder where indicated on PCB. Orientation is not important. Note: R3 is no longer used as of Rev 1.1 PCB
C3 | D3 | Locate and install the glass diode D3. Note that diodes are 'direction sensitive'. You must install it so the black stripe on the diode matches up with the white stripe on the PCB.
C4 | U2 (6N137) | The 6N137 is the opto isolator for the DCC signal into the Arduino. Orientation is very important. On the part there is a small embossed circle indicating Pin 1. This pin goes at the end of the stencil that has the U shaped notch in it. A further check is that Pin 1 goes to the square solder pad (the other 7 solder pads for this 8 pin DIP are round.). Using an 8 pin DIP socket is possible if desired and if header pins are sued for the Arduino.
C5 | J9 | If you ARE powering the board by DCC do not modifiy the circuit board and this header pin is not needed. This header pin is used to inject a DCC signal into the decoder circuitry when you are NOT powering the board by DCC. NOTE: If this is your situation then there are two traces on the bottom of the board that must also be scratched open (Isolation points marked with an X). J9 is a 90 degree 2 pin male header.
Step | TEST | Observation
T5 | Visual | A quick visual check verifying component placement and no solder splatter.
Arduino |  |  | Figure 3
D1 | Arduino NANO R3 | Some Arduino NANO's are not assembled. All this means is the header pins must be soldered to the Arduino board itself before the Arduino can be used. If this is the case assemble your Arduino now and come back. The Arduino should look like as shown at right.
D2 | NANO Header Pins | The Arduino NANO can be soldered directly to the PCB if you wish. Check beneath the board to ensure an air gap exists to the opto islator chip mounted below. Optionally (my preference) is to use female Header Pins so the NANO is socketed to the PCB. A seperate detail page is included for preparing the female header pins should you wish to do this.
D3 | Optionally Install I/O Header Pins to match your requirements. | The PCB has the facility for a large number of header pins for the input and output pins of the Arduino. Referring to the schematic at right the pins will be installed as vertical runs of 4 pins which can be colour coded. (V = Red, G = Black, S = Yellow. See photo tab for my example). The colour is cosmetic and does not affect the functionality of course. In use these terminals will be used as a horizontal set of 3 ( S, V, G). There is also a 4 pin header for I2C communications. | Figure 4
Step | TEST | Observation
T6 | Visual Check | Install the Arduino and verify it is the right way round. The USB plug on your NANO should be on the opposite side from the power screw terminals installed earlier.
T7 | Its alive! | Apply your input power as was done previously. Most Arduinos ship with a factory default blink program installed. If this is the case upon power up one of The NANO's on board LEDs should blink. Note: No USB cable is needed - the PCB is running from the power supply you finished earlier. You may wish to use a USB cable and verify you can load an example program into the NANO for added confidence.
T8 | Turn off and Disconnect Power | If all tests have passed then proceed to the next section.
Figure 2
Figure 3
Figure 4

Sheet: Finish Up
 | MaxDuino Assembly Instructions R1.1
 | Known Issues | None.
Step | Action | Comments
RGB NeoPixel (optional)
E1 | D4 WS2812 NeoPixel | This is a surface mount component, rectangular in shape, with 4 small solder tabs near the corners. Orientation is important. Notice on chip itself there is a small triangular cutout in one corner. This is indicating the ground pin location and it matches a small white stencil triangle on the PCB (Figure 6). To install this component melt a small dab of solder on the ground pin pad near the triangle, then put the chip in location over all four pads and reheat that one pad without letting the chip move. Double check the orientation. and proceed to apply dabs of solder to the other 3 corners. If you are equipped to use solder paste on the pads that is also an option of course. | Figure 5 Figure 6
E2 | R13 (330R) | Install and solder where indicated on PCB. Orientation is not important.
DFRobot MP3 Player (optional)
F1 | R5 (680R), R6 (1K) | Install and solder where indicated on PCB. Orientation is not important. Note: these resistors will be under the DFRobot module and cannot easily be retrofitted if you omit them now. | Figure 7
F2 | C6 (104) | Install and solder where indicated on PCB. Orientation is not important.
F3 | U4 DF-Robot MP3 Module | My preference here is to install female header pins similar to what was done for the Arduino. Alternately the player can be soldered directly to the PCB however note there are resistors in the space under the module. The MP3 module is installed so that the SD card slot is facing to the outside edge of the PCB. Once the leads are aligned with the holes (a little gentle poking and prodding might be needed) push the module so that about 1 mm of the leads protrude through the bottom of the PCB. This is not critical but you don't want to damage or press against the resistors you just installed underneath.
F4 | J19 | Solder in the Screw terminals for the speaker connection to MP3 player.
RS-485 Communications to Arduino (optional)
G1 | R7 (120R), R8 (20K) R9 (20K), R10 (10K) R11 (10K), R12 (10K) | Install and solder where indicated on PCB. Orientation is not important. | Figure 8
G2 | C7 (104) | Install and solder where indicated on PCB. Orientation is not important.
G3 | JR7 EOL Jumper | Near the EOL resistor R7 is a two pin header. If a jumper is installed on this headrer R7 is brought into the circuit as an end of Line resistor. With no jumper installed R7 is not in circuit. There should only ever be two EOL resistors in any one RS485 network (One of those is normally in the USB interface at the computer end of the network.) Thus only one MAxDuino needs to have a R7 jumper installed.
G4 | U3 (MAX485) | The MAX 485 chip is an 8 pin Dual in Line package. It can be socketed if desired. Be sure to observe orientation with the U shaped notch on the PCB.
G5 | J16, J17 RS485 out / in | Solder in the Screw terminals for the RS485 network connection. Note: the two sets of RS485 screw terminals are in parallel with each other. They facilitate daisy chaining of the network without needing any external terminals.
Step | TEST | Observation
T9 | Final Check | It is recommended to repeat the power test at this stage as all of the components are now installed. Note: At this point of the build and depending on your input voltage the regulator might get very slightly warm but under no circumstances should it be too hot to touch.
 | Software Tests | At this point the board is built and presumed operational. Next various test programs can be downloaded to the Arduino in order to verify correct operation of each of the on board subsytems.
 |  | A large white square of stencil area is provided for you to write (using a sharpie marker for example) a letter or number code so you can track individual boards should you wish.
Figure 5
Figure 6
Figure 7
Figure 8

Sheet: Photos
MaxDuino Photos
 | General | A small bead of blue tac putty is very handy for holding small parts into the PCB while you flip it over and solder them. Only solder one lead on one component and then check to make sure that component is seated properly and oriented the correct way around. Then remove the blue tack and resume soldering the other leads.
 | Check your Work Frequently | Typical Printed Circuit Board (PCB) shown
 |  | Look carefully at each solder connection to ensure it is good.
 |  | Too much solder is as bad as too little.
 |  | A nice shiny volcano shape is what you are after.
 |  | Also look for bridging or solder splatter..
 |  | In this photo the clear coating from the manufacturing process has bubbled in couple of places (from the heat of soldering iron).
 |  | This is perfectly ok but is worth a close look to ensure that is all it is.
 | Power Supply Section | For reference here is the power supply section.
 |  | Note capacitors (black cylinders) come in various physical sizes. Voltage rating of top one should be at least 16 volts, and bottom one at least 10 Volts. No issues with using one rated higher than needed.
 |  | I have used a red 2 pin header for the Vin_En (Vin Enable) jumper but this is cosmetic.
 |  | If a header jumper pin were installed here then the INPUT to the voltage regulator is then also being supplied to the Vin pin on the Nano. The Nano could then use its own on board 5 volt regulator. (And the L7805 voltage regulator on this PCB would not be needed - but power current would be limited to what the arduino can supply.) With no jumper installed the large 5 volt regulator here provides 5 volts directly to the NANO.
 |  | The second photo shows how to check the proper operation of the regulator. (using an earlier version of the PCB but idea is the same)
 |  | Note each of the unoccupied 3 pin header locations has both a 5 volt pin (in the middle) and a ground pin (on the right). My meter probes are using these easily accessable holes and are giving the reading of 5.032 volts. On R1 and newer PCB the tops of the 5Volt screw terminals could be used also.
 | Arduino | Almost fully assembled board ready for testing.
 |  | At this point in time I was awaiting delivery of the bare neopixel chip.
 |  | The Arduino I/O pnis have been installed in a colour coded fashion.
 |  | I used all yellow header pins for the I2C header. Strictly speaking I should have used red for the +5, black for Gnd just to maintain colour consistency with the other headers.
 |  | TIP: Only solder one pin of any header and then check to make sure it is snug to the board. If it is not remelt the one pin and make it so. Only then solder the other pins. If a header is fully soldered in it is then difficult to melt all four pins to re-level it.
 |  | Only do one header at a time.

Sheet: Arduino Header Pins
Arduinos can be soldered directly to the PCB
However I prefer to 'socket them' using a strip of female header pins. These can be bought very inexpensively and come in strips of '40'.
Link here (https://www.aliexpress.com/item/1005004363623073.html?_t=pvid:70a28d80-54f2-4a0f-a388-745529540997)
Here is how to cut them to length easily.
1) plug the strip of header pins onto the Arduino so the end arduino pin aligns with the end header pin. Here this is on the left side and the excess header pins all stick out to the right.
2) Locate where last Ardiuno PIN plugs in and then using needlenose pliers grab the next pin and gently pull it up and out of the housing. You can see the removed pin at the bottom of the photograph - it looks like a small tuning fork.
3) Do this on both sides as circled.
4) Remove the header pins from the Arduino and using a straight edge and sharp knife gently score the edge right where the pin was removed. A few passes pressing lightly is better than trying to press too hard. You do NOT need to cut through .. Only scoring is needed.
5) Then Between your fingers flex the hedaer pins back and forth around the score line. It should snap cleanly.
6) Here is the end product mounted to our Arduino.
7) I find it easiest to solder this 3 piece assembly Into the PCB. (only one pin on each side!). - Check for alignment and snugness to the PCB - (Remelt the solder and rework as needed.) - Finally solder all of the additional pins. Then you can test removing and reinserting the Arduino from the header pins. Verify it is installed the right way round!

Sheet: PCB R1 Testing
Test | Main Feature | Pass Fail | When Tested | Tested By | Comments
1 | Power Supply | Pass | 2023-06-13 | AL | 12VDC In produced 5.01 volts. USB power allowed loading sketch, main on board LED Lit DCC In works but heat sink reccomended depending on DCC voltage.
2 | Operation | Pass | 2023-06-13 | AL | Loaded blink program which ran as expected.
3 | I/O Headers | Pass | 2023-06-15 | AL | Used 3 pin dupont header and an IR sensor. Verified all 3 pin headers worked as digital inputs. (with MP3 test below)
4 | MP3 | Pass | 2023-06-15 | AL | Sketch triggered an MP3 track from an IR sensor. Modified and relaoded for each of the pins associated with a 3 pin header.
5 | I2C | Pass | 2023-06-15 | AL | Loaded a modified version of the SSD21306 eample sketch to prove I2C was working.
6 | RS485 | Pass | 2023-06-16 | AL | Use a MaxDuiono as a CMRI node then use JMRI to activate various sounds.
7 | DCC Decode | Pass | 2023-06-28 | AL | Power Maxduino from DCC and try implementing a DCC Decoder. Found - noisy power shield prevented decoding. (fixed). Revised R and C values were required. R1.1
8 | NeoPixel | Pass | 2023-06-19 | AL | Neopixel chip soldered onto board and 3 color blink program runs fine (using pin D4)

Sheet: IMPROVEMENT ITEMS
Ref # | What | Status | Comment
1 | Improve these Assembly instructions | Done | R1.1
2 | Minor Stencil Improvements - add white triangle on ground pin of NeoPixel | Done | R1.1
3 | Dedicated test points (TP) for input power, 5 volt power | Rejected | Use existing test points on partially assembled PCB
4 | Consideradding LED's to indicate Rx/Rx activity (eg RS485 comm's) | Rejected | NANO has these LED's on board already.
5
6
7
8

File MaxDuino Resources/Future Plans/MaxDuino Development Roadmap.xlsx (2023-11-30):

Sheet: 5YP_Aug_2023
 |  | MaxDuino Version => | 1.0 | 1.1 | 1.2-1.4 | 1.5 |  |  |  |  |  |  | 2.0
5YP Planning Year |  |  | 1 |  |  |  | 2 |  |  |  | 3 |  |  |  | 4 |  |  |  | 5
Calendar Year |  |  | 2023 |  |  |  | 2024 |  |  |  | 2025 |  |  |  | 2026 |  |  |  | 2027
Section | Objective | Tech | Q1 | Q2 | Q3 | Q4 | Q1 | Q2 | Q3 | Q4 | Q1 | Q2 | Q3 | Q4 | Q1 | Q2 | Q3 | Q4 | Q1 | Q2 | Q3 | Q4
Platform | Easy to assemble with as many standard parts as practical. | 2 layer TH PCB
Power Supply | Robust and usable with most layouts accessory power | Flexible |  |  |  | Discretes
SBC | Functional but Inexpensive | NANO 3.x |  |  |  |  |  |  | Migrate to ESP32?
I2C | Drive OLED displays | Yes
RS485 | Communications and growth | Yes |  |  | Mod |  | RJ45
MP3 | Animations | Yes
NeoPixel | Diagnositics | single SM 2812B + Ext |  |  | Mod
I/O | Sensor inputs, servo outputs | Up to 15
DCC Decode | Stationary accessory decode | Yes | X |  | X
SPI | Communications and growth | In Ver 2.0 |  |  |  |  |  |  | Add ?
Canbus | MERG CBUS intergration | In Ver 2.0 |  |  |  |  |  |  | Add ?

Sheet: RAIL_Aug_2023
RAIL
When | Item | Who | Status
2023 Q3 | Gather MERG feedback and areas for improvement Publish this plan as a starting point and receive comments. | AL | Closed
2023 Q3-Q4 | Redesign PCB to R1.2 adding headers for Proposal 1, 2 & 3. Also address deficiencies list 1 and 2 Develop an initial appliance like application. Test for enthusiasm. By Year end this needs to be a team effort. (or you get what it is ) | AL | Closed
2024 Q1-Q4 | Promote within MERG including forming a working team to steward this roadmap. Develop several appliance like applications. Test for thoughts on MaxDuino education. (curriculum, format delivery etc) |  | New
2024 Q4 | Go-No-Go decision re V2 - full on redesign PCB to R2 with a NANO-ESP32 processor, adding WifI plus dual core 32 bit processing at espense of 3.3v I/O |  | Investigating

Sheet: Current Proposals
Proposals |  |  |  |  |  | Proposed Version | Status
No | 5YP Colour | Description | Impact if Accepted | Impact if Rejected | Next Step if Proceed
1 |  | Add SPI (Header) to MaxDuino | SPI devices can be accomodated. Requires redesign of MP3 to use other pins. Loss of some GPIO header pins Significant testing of software serial on new pins. | None (No SPI) | Determine header pins and order. Update Schem, PCB, Docs | 2.0 | Investigating
2 |  | Add CANBUS (via Header) to MaxDuino | CBUS devices can be accomodated via external board. (Requires SPI above) | None (No CBUS) | Determine header pins and order. Update Schem, PCB, Docs | 2.0 | Investigating
4 |  | Change SBC to an ESP32 solution (full PCB redesign) | Technically more capable. Adds native WiFi networking (inc WebServer) Adds language choices. Needs All new applications Needs All new documentation | No immediate change. Potential obsolecence of NANO | Weigh pros and cons carefully before proceeding. ESP32 module or native chip? | 2.0 | Investigating
3 |  | Modify so that 'S' pin of D4 header can be supplied from Dout of NeoPixel OR direct from D4 when no on board NP is installed. This is tied to deficiency #2 | On board NP is always index 0, External NP start at index 1 (on D4 header) Build time decision with on board NP | Current design has on board NP at index 0 and first external NP is also starting at address 0 (overlapping). Restricts usage of on board NP and impacts animations. | Update Schem, PCB, Docs | 1.2 | Closed | SCH modified PCB Artwork Complete Test articles made Testing Complete
5 |  | Modify RS485 so that DE/RE are driven from separate pins to allow for ICSP. This is tied to deficiency #1 | Allows for ICSP One more GP I/O pin will serve a dual purpose. | Remove NANO for reprogramming if RS485 must noe be affected. | Update Schem, PCB, Docs | 1.4 | Closed | ditto

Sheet: Current Deficiencies
 |  | Deficiency List
Item | Applies to | Known Deficienices | How To Reproduce Deficiency | Workaround / Alternate | Impact | Probability | Proposed Remedy | Consequences of Remedy | Decision | Status
1 | V1.1 | RS485 DE and RE are driven by same pin. Both cannot be disabled as is needed for ICSP of Arduino. | Kisnet with multiple Arduinos. Use USB to program one and it disrupts all communications. | Always use header pins and socket the Nano. Reprogram NANO only out of circuit | Disrupts communications | 100% | Redesign SCH and PCB to add second pin. Standard pins to use are D2/D3. | Knock on effect for D3 (Thr DCC decoding pin.) | Include in V1.2 | Closed
2 | V1.1 | Both the on board Neopixel (NP) and the IO header pin D4 are driven from Arduino pin 4 directly. Using index 0 both NP will blink at same time. | With on board NP installed add external NP string to header D4. Run NP test program. Two NP's will blink (both are index 0) | Do not install on board NP. | Diagnostic output will impact animation displays. | 100% | Drive IO signal pin (D4 header) from Dout of the on board NP | Use of D4 requires on board NP or some sort of bypass arrangement | Include in V1.2 | Closed
3 | V1.2 | When addressing item 1 above I moved DCC decoding to a new pin. Turned out that new pin did not support required interrupts. | DCC Dcecoding failed test. | Use R1.1 PCB for DCC Decoding. | No DCC Decoding | 100% | Redesign SCH and PCB to put DE/RE pins on D2 and D5. Return DCC decoding to D3 pin. | New production of R1.3 | Include in V1.3 | Closed
4 | V1.3 | Some manual stencil items on the PCB were not properly updated. (Revision number for one). | Look | Ignore minor stencil items. | Minor | 100% | Fix stencil items in R1.4 While doing this rearrange order of D3 and D4 header pins | New production of R1.4 | Include in V1.4 | Closed

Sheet: Validations
Deficiency Status | Proposal Decisions | RAIL Status
 |  | New
Investigate | Insufficient Data | Investigating
Confirmed | Accepted | In Progress
Plan Developed | Rejected | Response TBC
In Design | Recycle (with comments) | Closed
In Manufacturing |  | Defer
Testing
Closed

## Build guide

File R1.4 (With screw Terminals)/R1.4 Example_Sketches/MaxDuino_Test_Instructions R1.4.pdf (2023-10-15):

Test No Area under test | Test Code | Rev Physical Parts Needed | Connections | Steps | Expected Outcome | Comments
1 | Neopixel | MaxDuino_Onboard_NeoBlink.ino | none | none | Load Sketch | on board Neopixel will cycle Red-Green-Blue | NeoPixel is on pin D4 and is always index [0] in a Fastled array.
2 | IO Header Pins | MaxDuino_IO_Check | A 3 wire sensor with 3 pin dupont header in pin order of S-V-G | plug in sensor observing pin order | By activating a one pin at a time the on board neopixel should change colour. | The NeoPixel will display a different colour for each pin activated. A6/A7 and D13 are not tested. | The purpose is only to test if the header pins are working. Plug in an external NeoPixel string to header pins D4 to test it.
3 | I2C | Maxduino_I2C_check_OLED_128x32 | 128x32 OLED display F-F Dupont jumper wire (Qty 4) | Connect display to I2C header, matching the 4 pins | Load Sketch | Display will cycle through some tests under control of the sketch. | I2C OLED displays normally have an I2C address of 0x3C or 0x3D
4 | MP3 | MaxDuino_MP3_Sound_Check.ino

Small 8 ohm speaker
micro sD card with mp3 folder containing mp3 sound tracks

speaker connected to the speaker
terminals | Load Sketch

A sound track should play upon power up. The "play next" command is issued every 6 seconds.

play order is determined by time stamp of file copy, NOT the file name or visible file time stamp.

5 | RS-485 | MaxDuino_RS485_MP3

USB to RS485 converter.
Pair of wires for RS485 comms A&B USB Cable for Arduino
Computer running JMRI

Use a pair of wires to connect the RS485 USB converter to the MaxDuino (matching the A and B terminals). Connect the USB converter to the PC. If only these two RS485 devices are involved enabling R7 is not necessary.

Establish a connection from JMRI to USB converter so that it becomes available to JMRI. (See Screen shot below) The CMRI node in Arduino test code is only listening on address

### 0 therefore in the lights table (1) define 'lights' for CMRI

addresses 1 => 7 and define sensors in the sensors table also on addresses 1-7

Bits 1 to 7 being toggled in JMRI/CMRI will be read by the Arduino which will cause lights 1-7 to follow the status. (loop back). The on board NeoPixel will change according to the highest bit that is set.

This test shows a minimum of functionality as a proof of operation of RS485.

6 | DCC Decoder | MaxDuino_DCC_Decoder | Jumper wires to power the MaxDuino from DCC

DCC Power to the power input connections on MaxDuino.
Note: The use of a heat sink on the 5 Volt regulator (Part 7805) is highly reccomended.

Load the sketch
Connect MaxDuino to a DCC source. (Leave unpowered). Initially nothing is being decoded as MaxDuino is unpowered.
Apply power to the module from a DCC supply. .

The serial monitor (@19.2K) will show accessory commands as they are received. The Arduino is listening for any accessory address less than 400

This test shows DCC decodimg for a wide range of addresses. In practice the sketch would respond to only a small number of addresses.

Test #5 - JMRI showing a CMRI connection to the USB / RS485 adaptor | Test #5 - In the lights table (1) Add a series of lights at addresses 1 through 7 (2) Toggle the bits using the buttons (3). The sensors table should update reflecting the current light status.

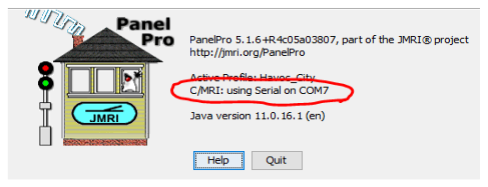
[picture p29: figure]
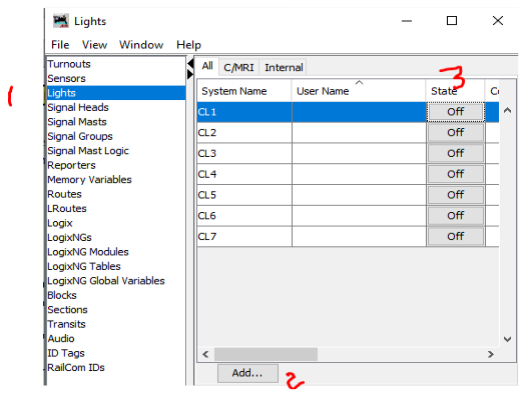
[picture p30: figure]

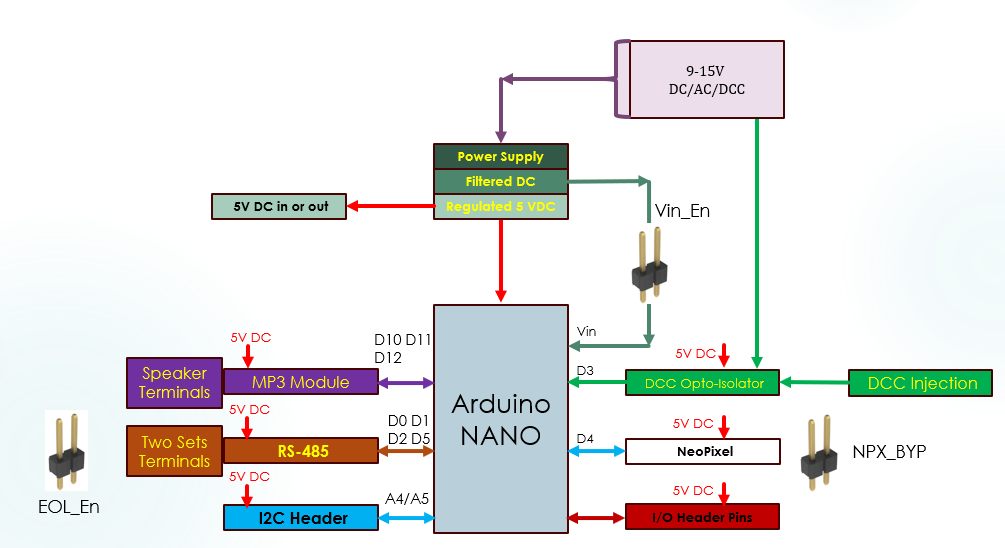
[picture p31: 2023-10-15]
MaxDuino Resources/Construction Photos/01 Figure 1 MaxDuino R1.4 Block Diagram.PNG

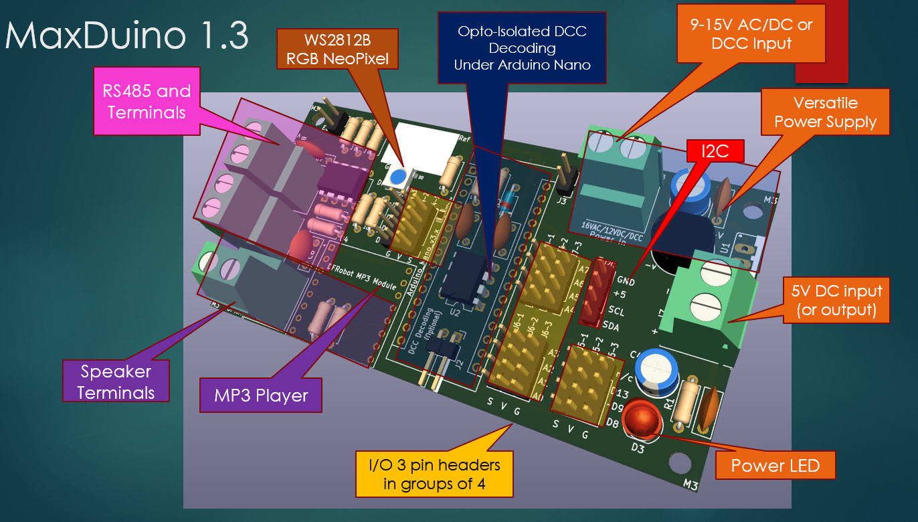
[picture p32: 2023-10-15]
MaxDuino Resources/Construction Photos/00 Figure 2 MaxDuino R1.3 3D View (annotated).PNG

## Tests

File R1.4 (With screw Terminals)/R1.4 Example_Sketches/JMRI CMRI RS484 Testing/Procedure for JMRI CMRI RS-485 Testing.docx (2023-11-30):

# Configuring a JMRI / CMRI Node

## A Step By Step Guide

To be used in for testing proper hardware operation of the MaxDuino PCB

The default Arduino RS-485 test sketch is preconfigured for:

- Speed of 19,200 bps
- CMRI Node Address 0 (with default settings this provides 24 ‘lights’ and ‘48’ sensors)
- The test sketch is listening for individual bits 1-7 coming from JMRI (lights) and then sets or clears the matching bit going to JMRI (the Sensor table)
- It also uses the on board NeoPixel on the MaxDuino PCB to indicate activity.

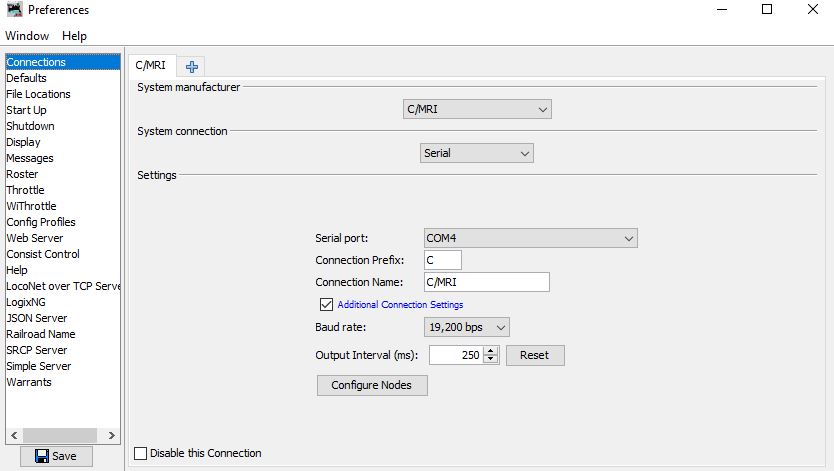
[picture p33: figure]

1 | | Make a new connection of Type CMRI. The COM port will be the one your USB/RS485 adaptor is plugged into. Check additional settings and ensure speed is set to 19200 bps as shown. This must match the Arduino sketch and that speed has been pre configured in the sketch.

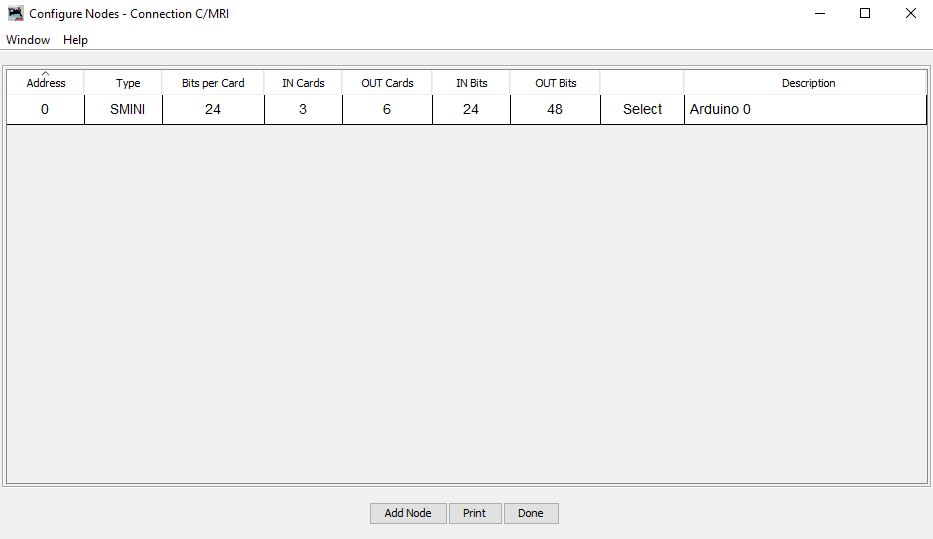
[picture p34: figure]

2 | | Notice at the bottom of the previous screen you have the option to configure nodes. If you click it the screen at right will appear (but without any rows). On this screen you will click Add Node at the bottom.

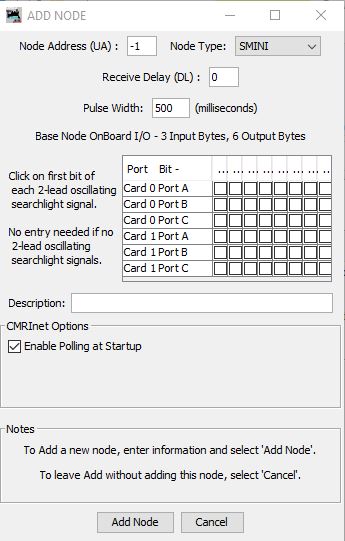
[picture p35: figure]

3 | | This pop up then appears. It looks rather busy but most can be ignored. The important item is the node address which defaults to -1 (meaning not configured). Change the address to 0 and click “Enable Polling at Start-up” and then “Add Node”. After this you should return to the previous screen and now the row for address 0 should be present.

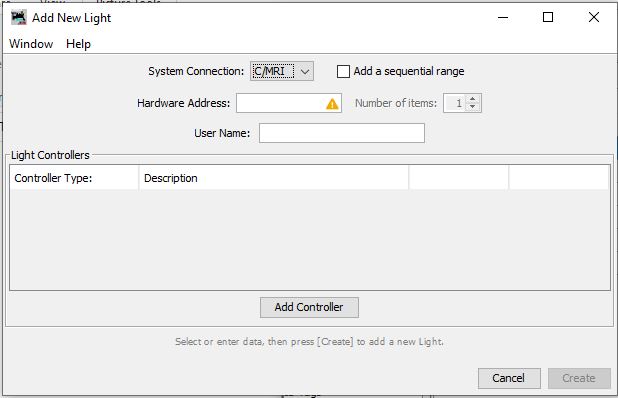
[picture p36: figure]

4 | | The previous steps have told JMRI we have a piece of hardware out there at address 0. Next we will configure individual devices at that address. Specifically go to the Lights table in JMRI and add a light. Use the CMRI connection and click add a sequential range. Start at address 1 and add 7 items

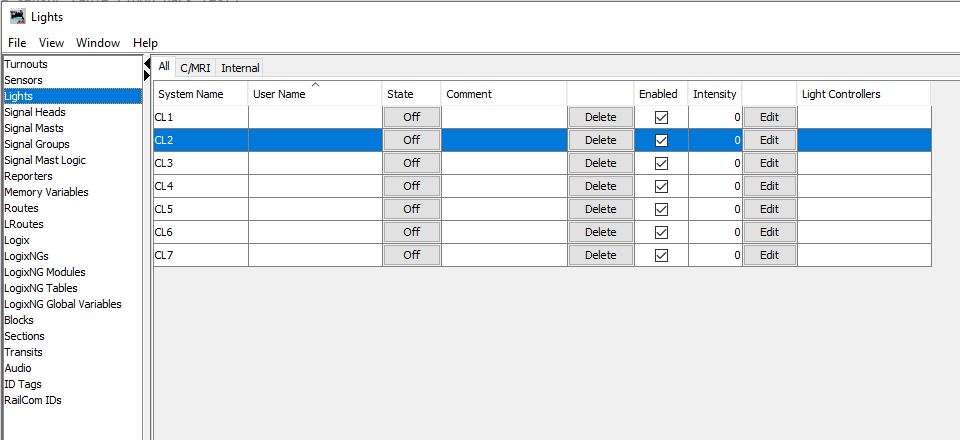
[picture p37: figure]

5 | | After the previous step the lights table should look like this. In JMRI a light is really and digital output, it does not matter if it used for a light or not.

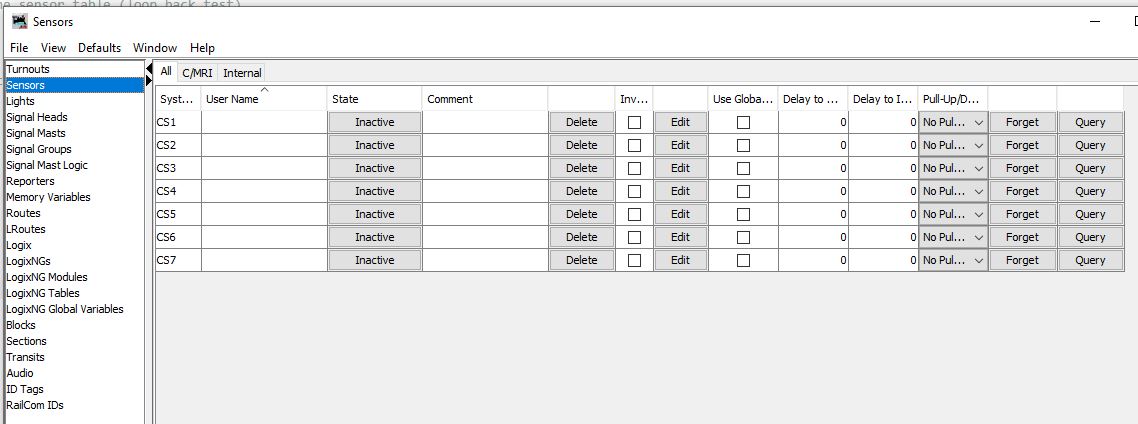
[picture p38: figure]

6 | | In a similar manner on the sensors table add a block of 7 sensors.

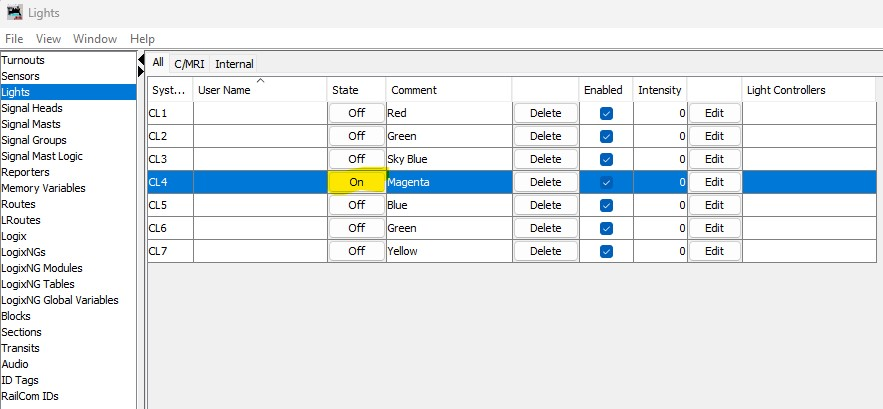
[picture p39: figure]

7 | | By clicking the state of a given light you toggle it from off to on and vice versa. (yellow highlight) That command goes out on the RS485, is detected by the Arduino running the CMRI emulation library at address 0. The sketch acts on that bit by turning on the NeoPixel and also turn on the matching bit in the sensor table.

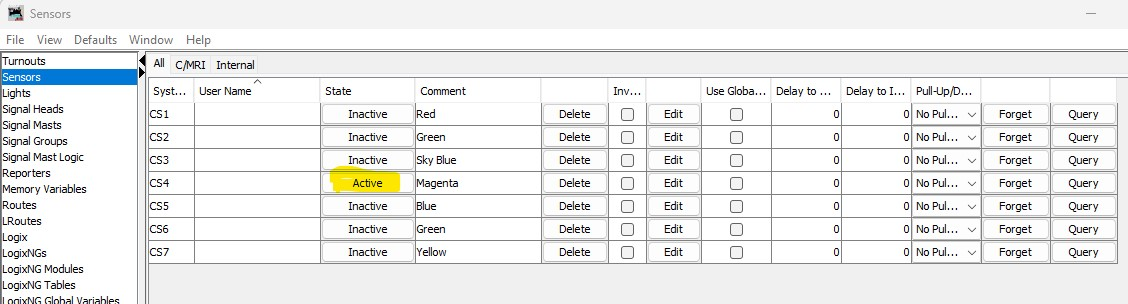
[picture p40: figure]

| | Here the matching bit has been set and read back. The Yellow Highlight is Showing where this sensor is reading Active now.

8

If toggling a bit in the lights table causes the NeoPixel to change colour you can be assured a command is going to the Arduino. /if the matching bit in the sensor table also toggles you also know sensor status is being returned back.

This is proof that basic communications is working. While this happening activity should be visible on the USB interface which normally has LED’s flickering to indicate traffic.

Adding additional nodes at additional addresses is simply repeating these steps and modifying the sketch to be listening on the new address. Dozens of nodes and hundreds of lights or sensors are possible.

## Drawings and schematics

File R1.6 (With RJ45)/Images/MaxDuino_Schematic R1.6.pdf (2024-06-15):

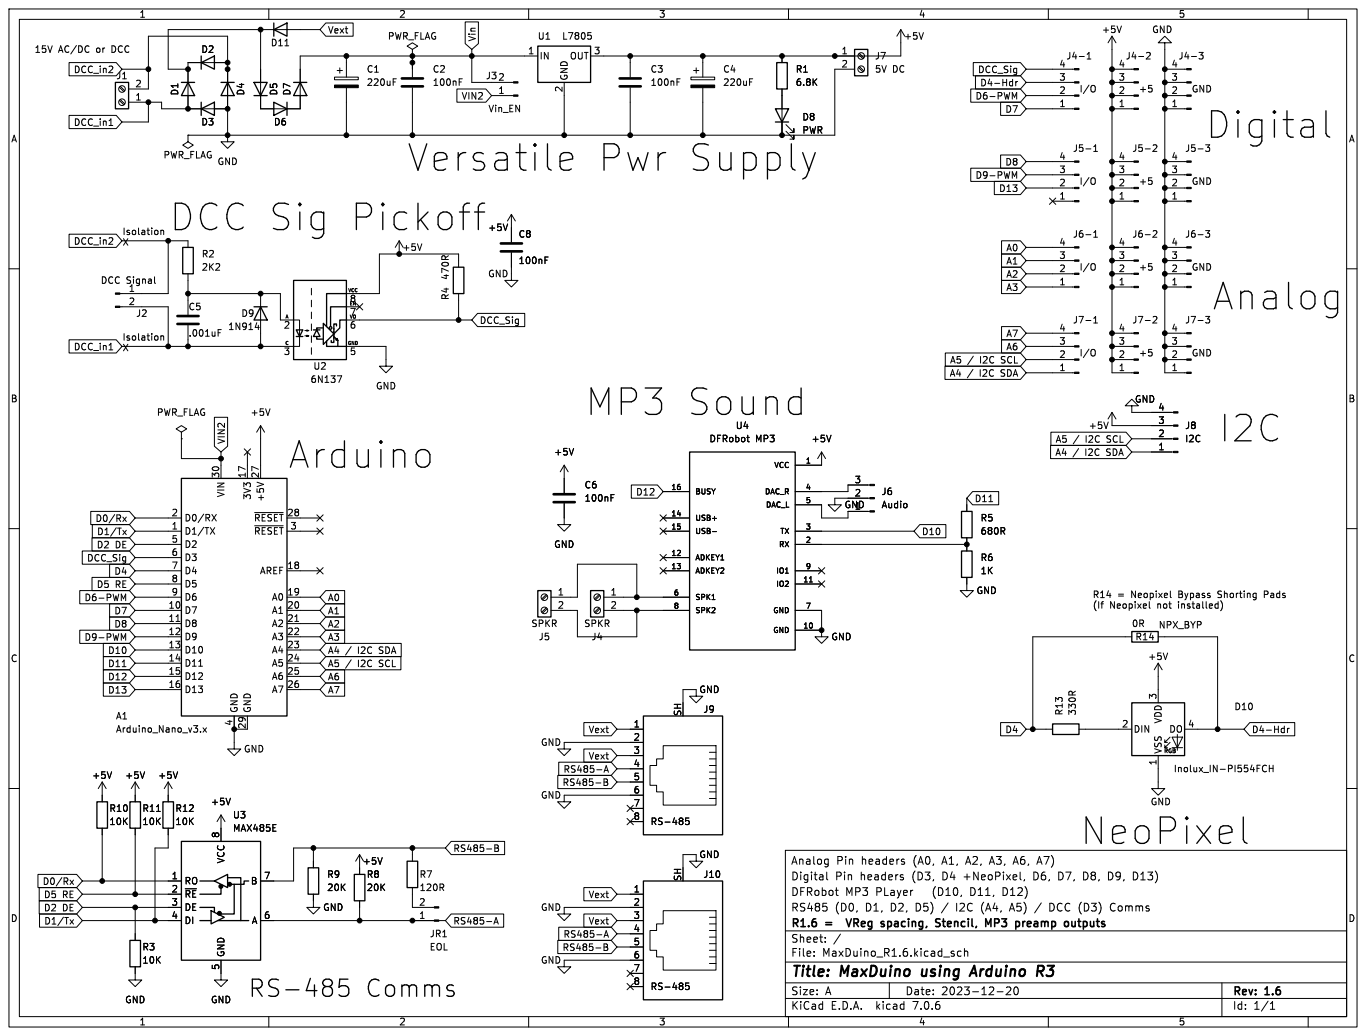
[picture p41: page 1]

A3A5 / I2C SCL D2 DE D0/Rx D6-PWM

(If Neopixel not installed)

Id: 1/1 Title: MaxDuino using Arduino R3

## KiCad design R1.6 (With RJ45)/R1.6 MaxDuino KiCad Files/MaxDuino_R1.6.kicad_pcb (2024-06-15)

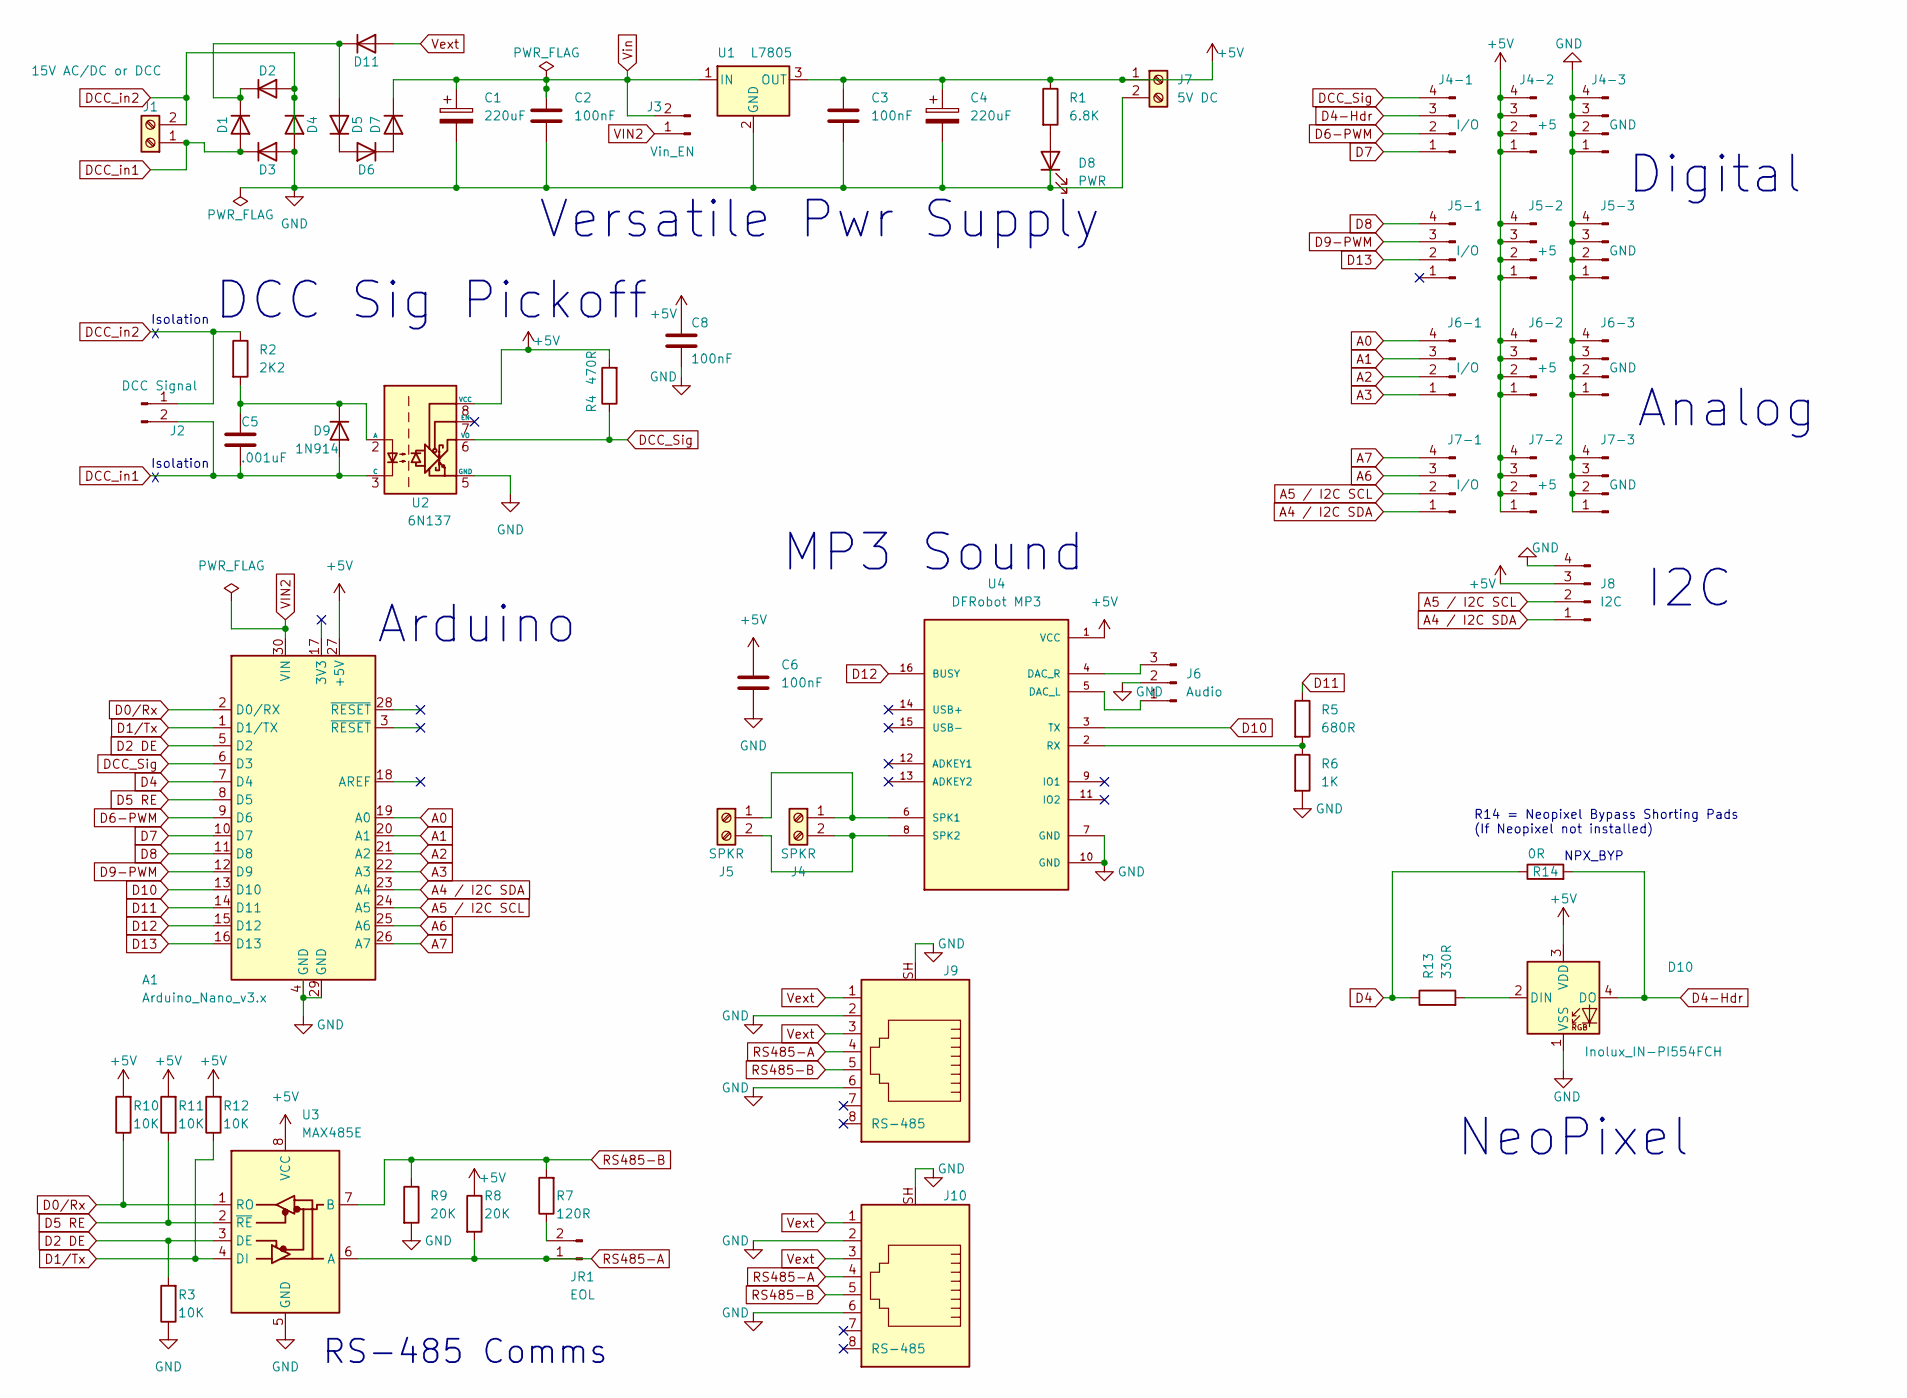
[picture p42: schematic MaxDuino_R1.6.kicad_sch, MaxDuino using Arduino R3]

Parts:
A1: Arduino_Nano_v3.x; Arduino_Nano
C1, C4: 220uF; CP_Radial_D6.3mm_P2.50mm
C2, C3, C6, C8: 100nF; C_Disc_D7.0mm_W2.5mm_P5.00mm
C5: .001uF; C_Disc_D7.0mm_W2.5mm_P5.00mm
D1, D2, D3, D4, D5, D6, D7, D11: 1N4001; D_DO-41_SOD81_P10.16mm_Horizontal
D8: PWR; LED_D5.0mm
D9: 1N914; D_DO-35_SOD27_P7.62mm_Horizontal
D10: Inolux_IN-PI554FCH; LED_Inolux_IN-PI554FCH_PLCC4_5.0x5.0mm_P3.2mm
J1: 15V AC/DC or DCC; TerminalBlock_Phoenix_MKDS-3-2-5.08_1x02_P5.08mm_Horizontal
J2: DCC Signal; PinHeader_1x02_P2.54mm_Horizontal
J3: Vin_EN; PinHeader_1x02_P2.54mm_Vertical
J4, J5: SPKR; PinHeader_1x02_P2.54mm_Vertical
J4-1, J5-1, J6-1, J7-1: I/O; PinHeader_1x04_P2.54mm_Vertical
J4-2, J5-2, J6-2, J7-2: +5; PinHeader_1x04_P2.54mm_Vertical
J4-3, J5-3, J6-3, J7-3: GND; PinHeader_1x04_P2.54mm_Vertical
J6: Audio; PinHeader_1x03_P2.54mm_Vertical
J7: 5V DC; TerminalBlock_Phoenix_MKDS-3-2-5.08_1x02_P5.08mm_Horizontal
J8: I2C; PinHeader_1x04_P2.54mm_Vertical
J9, J10: RS-485; RJ45_Ninigi_GE
JR1: EOL; PinHeader_1x02_P2.54mm_Vertical
R1: 6.8K; R_Axial_DIN0207_L6.3mm_D2.5mm_P7.62mm_Horizontal
R2: 2K2; R_Axial_DIN0207_L6.3mm_D2.5mm_P7.62mm_Horizontal
R3, R10, R11, R12: 10K; R_Axial_DIN0207_L6.3mm_D2.5mm_P7.62mm_Horizontal
R4: 470R; R_Axial_DIN0207_L6.3mm_D2.5mm_P7.62mm_Horizontal
R5: 680R; R_Axial_DIN0207_L6.3mm_D2.5mm_P7.62mm_Horizontal
R6: 1K; R_Axial_DIN0207_L6.3mm_D2.5mm_P7.62mm_Horizontal
R7: 120R; R_Axial_DIN0207_L6.3mm_D2.5mm_P7.62mm_Horizontal
R8, R9: 20K; R_Axial_DIN0207_L6.3mm_D2.5mm_P7.62mm_Horizontal
R13: 330R; R_Axial_DIN0207_L6.3mm_D2.5mm_P7.62mm_Horizontal
R14: 0R; R_0805_2012Metric
U1: L7805; TO-220-3_Vertical
U2: 6N137; DIP-8_W7.62mm
U3: MAX485E; DIP-8_W7.62mm
U4: DFRobot MP3; MODULE_DFR0299

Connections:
+5V: A1.27 (+5V), C3.1, C4.1, C6.1, C8.1, D10.3 (VDD), J4-2.1, J4-2.2, J4-2.3, J4-2.4, J5-2.1, J5-2.2, J5-2.3, J5-2.4, J6-2.1, J6-2.2, J6-2.3, J6-2.4, J7.1, J7-2.1, J7-2.2, J7-2.3, J7-2.4, J8.3, R1.1, R4.2, R8.1, R10.2, R11.2, R12.2, U1.3 (OUT), U2.8 (VCC), U3.8 (VCC), U4.1 (VCC)
A0: A1.19 (A0), J6-1.4
A1: A1.20 (A1), J6-1.3
A2: A1.21 (A2), J6-1.2
A3: A1.22 (A3), J6-1.1
A4 / I2C SDA: A1.23 (A4), J7-1.1, J8.1
A5 / I2C SCL: A1.24 (A5), J7-1.2, J8.2
A6: A1.25 (A6), J7-1.3
A7: A1.26 (A7), J7-1.4
D0/Rx: A1.2 (D0/RX), R10.1, U3.1 (RO)
D1/Tx: A1.1 (D1/TX), R12.1, U3.4 (DI)
D2 DE: A1.5 (D2), R3.2, U3.3 (DE)
D4: A1.7 (D4), R13.1, R14.1
D4-Hdr: D10.4 (DO), J4-1.3, R14.2
D5 RE: A1.8 (D5), R11.1, U3.2 (~RE)
D6-PWM: A1.9 (D6), J4-1.2
D7: A1.10 (D7), J4-1.1
D8: A1.11 (D8), J5-1.4
D9-PWM: A1.12 (D9), J5-1.3
D10: A1.13 (D10), U4.3 (TX)
D11: A1.14 (D11), R5.1
D12: A1.15 (D12), U4.16 (BUSY)
D13: A1.16 (D13), J5-1.2
DCC_Sig: A1.6 (D3), J4-1.4, R4.1, U2.6 (VO)
DCC_in1: C5.2, D1.2 (A), D3.1 (K), D9.2 (A), J1.1, J2.2, U2.3 (C)
DCC_in2: D2.2 (A), D4.1 (K), J1.2, J2.1, R2.1
GND: A1.4 (GND), A1.29 (GND), C1.2, C2.2, C3.2, C4.2, C6.2, C8.2, D3.2 (A), D4.2 (A), D8.1 (K), D10.1 (VSS), J4-3.1, J4-3.2, J4-3.3, J4-3.4, J5-3.1, J5-3.2, J5-3.3, J5-3.4, J6.2, J6-3.1, J6-3.2, J6-3.3, J6-3.4, J7.2, J7-3.1, J7-3.2, J7-3.3, J7-3.4, J8.4, J9.2, J9.6, J9.SH, J10.2, J10.6, J10.SH, R3.1, R6.2, R9.2, U1.2 (GND), U2.5 (GND), U3.5 (GND), U4.7 (GND), U4.10 (GND)
unnamed: D1.1 (K), D2.1 (K), D5.2 (A), D11.1 (K)
unnamed: D5.1 (K), D6.2 (A)
unnamed: D6.1 (K), D7.2 (A)
unnamed: D8.2 (A), R1.2
unnamed: C5.1, D9.1 (K), R2.2, U2.2 (A)
unnamed: D10.2 (DIN), R13.2
unnamed: J4.1, J5.1, U4.6 (SPK1)
unnamed: J4.2, J5.2, U4.8 (SPK2)
unnamed: J6.1, U4.5 (DAC_L)
unnamed: J6.3, U4.4 (DAC_R)
unnamed: JR1.2, R7.1
unnamed: R5.2, R6.1, U4.2 (RX)
RS485-A: J9.4, J10.4, JR1.1, R8.2, U3.6 (A)
RS485-B: J9.5, J10.5, R7.2, R9.1, U3.7 (B)
VIN2: A1.30 (VIN), J3.1
Vext: D11.2 (A), J9.1, J9.3, J10.1, J10.3
Vin: C1.1, C2.1, D7.1 (K), J3.2, U1.1 (IN)

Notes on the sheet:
RS-485 Comms
MP3 Sound
Digital
I2C
NeoPixel
DCC Sig Pickoff
NPX_BYP
R14 = Neopixel Bypass Shorting Pads (If Neopixel not installed)
Versatile Pwr Supply
Isolation X
Analog
Arduino

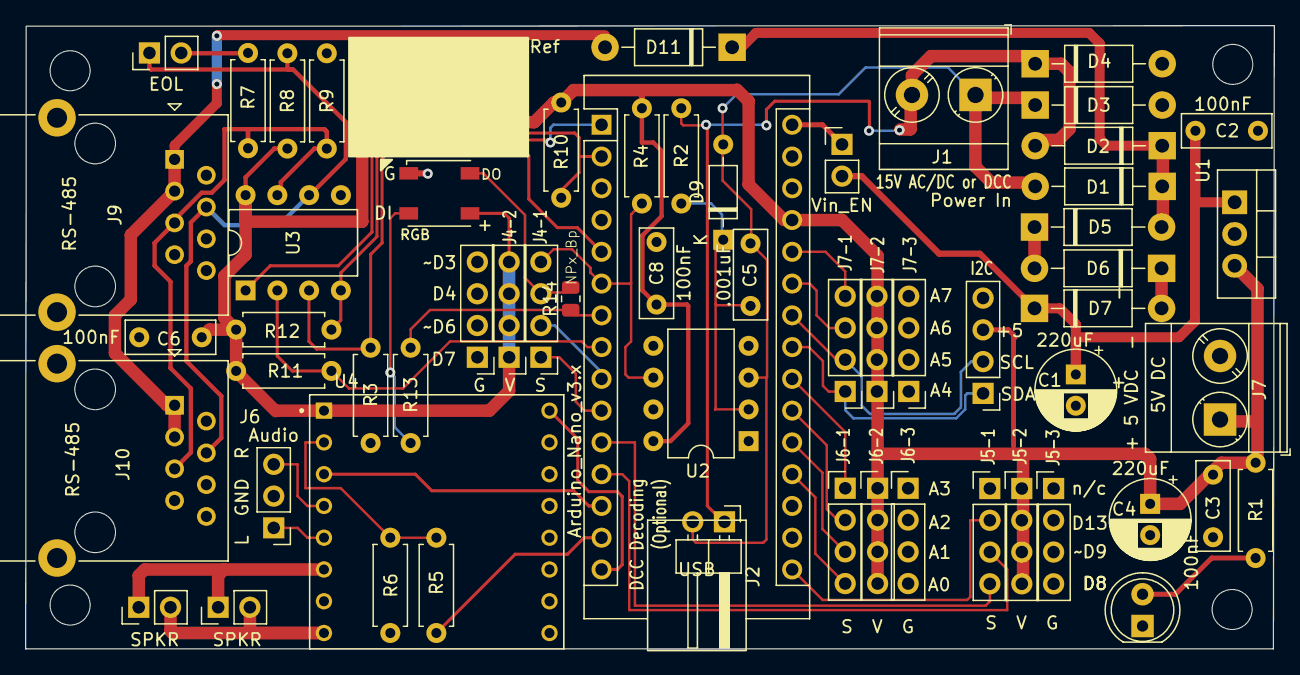
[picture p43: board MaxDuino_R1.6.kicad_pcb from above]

Board: 2 copper layers, 99.8 x 49.8 mm, 65 parts (1 on the bottom side), 44 nets.

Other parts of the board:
M3.1, M3.2, M3.3, M3.4: M3; MountingHole_3.2mm_M3
MERG: LOGO; MERG_LOGO

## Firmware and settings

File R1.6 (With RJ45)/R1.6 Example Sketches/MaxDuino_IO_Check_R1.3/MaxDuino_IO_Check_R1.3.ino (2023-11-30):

int VER_MAJ = 0;
int VER_MIN = 1;
int VER_BETA = 3;
// Testing all inputs except for A6/A7, D0-D4, D13
char* about = "I/O Header Pin Testing";
/******************************************************************************
   Demo code for testing the MAxDuino board (I/O pin headers)
   Defines all pins as inputs and then uses those pins to light  LED_BUILTIN and
   also the on board Neopixel. 
   The colour of the Neopixel is different for each input.
   The Purpose of this is simply to allow a quick test of the I/O header pins
   to ensure the board is working properly.
   The colour is not important as long as a change is observed.
   If no input is detected the NeoPixel should be black. (no light emitted)

   Hardware assumptions:
      MAXDuiono PCB with single bare chip WS2812 NeoPixel in place.
      I/O header pins installed
      Arduino NANO
  Software Assumptions:
      Libraries Listed below are available

  Test Plan
      Use a 3 wire sensor to activate each MaxDuino I/O pin in turn. 
      Alternate: Use a single jumper cable with two female dupont connectors
      and connect each input pin to ground one at a time.    
 ******************************************************************************/
#include <FastLED.h>

/*
  This routine defines **most** of the header pins as inputs.
  It reads them and outputs a different colour to the NeoPixel according to which one was detected.
  On the MaxDuiono choices are   4,5,6,7  8,9,13   A0,A1,A2,A3   A4,A5,A6,A7
                                 =======  ======   ===========   ===========
  The grouping above shows header arrangement for the pins.
  
  Notes: 
  **Pins Not Tested**
  Pins D0 and D1 (Rx/Tx) communications are not brought out to header pins.
  Pin  D2 is used for RS485 Comms  and is not brought out to a header pin. (Test with RS485)
  Pin  D4 is available on the headers. Optionally an external NeoPixel strip could be connected (Max of 10 elements).
  Pin  D5 is used for RS485 Comms  and is not brought out to a header pin. (Test with RS485)
  Pin D13 is also available on the headers but this is the LED_BUILTIN so additional testing is of limited value.
  Because pins A6 and A7 are analog inputs that lack digital input capability they are not tested.
  
  **Pins Tested**
  Per list defined below.
*/
// For NeoPixel
#define NUM_LEDS 11  // How many NeoPixels in the strip? (one on board plus up to 10 external)
#define DATA_PIN 4   // An external NeoPixel strip could be connected to this header also.
//  Define Input Pins
#define Input_pin1 3  // Available on the headers but note this pin is also used for DCC Comms. (Will also test with DCC)
#define Input_pin2 6
#define Input_pin3 7
#define Input_pin4 8
#define Input_pin5 9
// #define Input_pin6 13 // Pin 13 not used here. (LED_BUILTIN)
#define Input_pin7 A0
#define Input_pin8 A1
#define Input_pin9 A2
#define Input_pin10 A3
#define Input_pin11 A4
#define Input_pin12 A5
// Pin A6 not used here. (no digital input)
// Pin A7 not used here. (no digital input)

#define activated false  // some sensors are active low, some are active high. This allows a quick toggle

int currentInput = 0;   // variable to hold the currently read input
int previousInput = 0;  // variable to hold the prior input so we can report on change only

// Define the array of leds
CRGB leds[NUM_LEDS];

void setup() {
  Serial.begin(19200);
  printConfig(about);
  FastLED.addLeds<NEOPIXEL, DATA_PIN>(leds, NUM_LEDS);  // GRB ordering is assumed

  // Set all pin modes
  pinMode(Input_pin1, INPUT_PULLUP);
  pinMode(Input_pin2, INPUT_PULLUP);
  pinMode(Input_pin3, INPUT_PULLUP);
  pinMode(Input_pin4, INPUT_PULLUP);
  pinMode(Input_pin5, INPUT_PULLUP);
  // pinMode(Input_pin6, INPUT_PULLUP);
  pinMode(Input_pin7, INPUT_PULLUP);
  pinMode(Input_pin8, INPUT_PULLUP);
  pinMode(Input_pin9, INPUT_PULLUP);
  pinMode(Input_pin10, INPUT_PULLUP);
  pinMode(Input_pin11, INPUT_PULLUP);
  pinMode(Input_pin12, INPUT_PULLUP);
  pinMode(LED_BUILTIN, OUTPUT);
}

void loop() {
  currentInput = 0;
  if (digitalRead(Input_pin1) == activated) { currentInput = 1; }
  if (digitalRead(Input_pin2) == activated) { currentInput = 2; }
  if (digitalRead(Input_pin3) == activated) { currentInput = 3; }
  if (digitalRead(Input_pin4) == activated) { currentInput = 4; }
  if (digitalRead(Input_pin5) == activated) { currentInput = 5; }
  //  if (digitalRead(Input_pin6) == activated) { currentInput = 6; }
  if (digitalRead(Input_pin7) == activated) { currentInput = 7; }
  if (digitalRead(Input_pin8) == activated) { currentInput = 8; }
  if (digitalRead(Input_pin9) == activated) { currentInput = 9; }
  if (digitalRead(Input_pin10) == activated) { currentInput = 10; }
  if (digitalRead(Input_pin11) == activated) { currentInput = 11; }
  if (digitalRead(Input_pin12) == activated) { currentInput = 12; }

  if (previousInput != currentInput) {  // Report only on change of value
    Serial.print("Current Input: ");
    Serial.println(currentInput);
    previousInput = currentInput;
  }

  // below covers all of the inputs with distinct colours.
  // As long as a colour change is obseved then the pin header is obviously working.
  switch (currentInput) {
    case 0:
      for (int i = 0; i < NUM_LEDS; i++) {
        leds[i] = CRGB::Black;
      }
      break;
    case 1:
      leds[0] = CRGB::DeepPink;
      leds[1] = CRGB::DeepPink;
      break;
    case 2:
      leds[0] = CRGB::Blue;
      leds[2] = CRGB::Blue;
      break;
    case 3:
      leds[0] = CRGB::Yellow;
      leds[3] = CRGB::Yellow;
      break;
    case 4:
      leds[0] = CRGB::SeaGreen;
      leds[4] = CRGB::SeaGreen;
      break;
    case 5:
      leds[0] = CRGB::Lime;
      leds[5] = CRGB::Lime;
      break;
    case 6:
      leds[0] = CRGB::Red;
      leds[6] = CRGB::Red;
      break;
    case 7:
      leds[0] = CRGB::Cyan;
      leds[7] = CRGB::Cyan;
      break;
    case 8:
      leds[0] = CRGB::Green;
      leds[8] = CRGB::Green;
      break;
    case 9:
      leds[0] = CRGB::Magenta;
      leds[9] = CRGB::Magenta;
      break;
    case 10:
      leds[0] = CRGB::DarkCyan;
      leds[10] = CRGB::DarkCyan;
      break;
    case 11:
      leds[0] = CRGB::HotPink;
      leds[1] = CRGB::HotPink;
      leds[10] = CRGB::HotPink;
      break;
    case 12:
      leds[0] = CRGB::Purple;
      leds[1] = CRGB::Purple;
      leds[2] = CRGB::Purple;
      break;
    default:
      leds[0] = CRGB::Red;
      leds[1] = CRGB::Red;
      leds[3] = CRGB::Red;
      leds[5] = CRGB::Red;
      leds[7] = CRGB::Red;
      leds[9] = CRGB::Red;
      break;
  }
  // This is for the NeoPixel (on board plus any externals on Header pin 4)
  FastLED.show();
  // Below is in addition to NeoPixel
  digitalWrite(LED_BUILTIN, (currentInput != 0));  // any non zero value turns on the builtin LED
}

void printConfig(const char* about) {
  /* 
    ************************************
    ** printConfig(const char* about) **
    ************************************

   A subroutine that prints out basic information about the running program.
   Intended to be called once early in the startup code.  When connected to
   serial monitor this reveals what program is actually loaded on a given Arduino.

   Prior to invoking (typically on the first four lines of your sketch)
   the following four variables must be defined. Alter the numbers to suit of course.

  int VER_MAJ = 0;
  int VER_MIN = 0;
  int VER_BETA = 1;
  char* about = "a few words about the sketch";
*/
  Serial.println(">");
  // Source code
  Serial.println(F(">         File = " __FILE__));
  Serial.print(F(">        About = "));
  Serial.println(about);

  // code version
  Serial.print(F("> Code version = "));
  Serial.print(VER_MAJ);
  Serial.print(F("."));
  Serial.print(VER_MIN);
  Serial.print(F("."));
  Serial.println(VER_BETA);

  // Compiler version
  Serial.println(F("> Compiled on  = " __DATE__ " at " __TIME__));
  Serial.print(F("> Compiler ver = "));
  Serial.println(__cplusplus);

  // copyright
  Serial.println(">");
  Serial.println(F(">    For MaxDuino by by Alan Lomax (MERG M8640) Oct 2023"));
  Serial.println(">");
}

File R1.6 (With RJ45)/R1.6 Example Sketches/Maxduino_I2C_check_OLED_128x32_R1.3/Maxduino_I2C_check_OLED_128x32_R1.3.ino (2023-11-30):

int VER_MAJ = 0;
int VER_MIN = 1;
int VER_BETA = 3;
/**************************************************************************
 This example is for a 128x32 pixel display using I2C to communicate
 3 pins are required to interface (two I2C and one reset).

 Adafruit invests time and resources providing this open
 source code, please support Adafruit and open-source
 hardware by purchasing products from Adafruit!

 Written by Limor Fried/Ladyada for Adafruit Industries,
 with contributions from the open source community.
 BSD license, check license.txt for more information
 All text above, and the splash screen below must be
 included in any redistribution.

Modifed by AL only to include basic information on the debug console. 

 **************************************************************************/

#include <Wire.h>
#include <Adafruit_GFX.h>
#include <Adafruit_SSD1306.h>

#define SCREEN_WIDTH 128  // OLED display width, in pixels
#define SCREEN_HEIGHT 32  // OLED display height, in pixels

// Declaration for an SSD1306 display connected to I2C (SDA, SCL pins)
// The pins for I2C are defined by the Wire-library.
// On an arduino NANO:       A4(SDA), A5(SCL)
#define OLED_RESET -1        // Reset pin # (or -1 if sharing Arduino reset pin)
#define SCREEN_ADDRESS 0x3C  ///< See datasheet for Address; 0x3D for 128x64, 0x3C for 128x32
Adafruit_SSD1306 display(SCREEN_WIDTH, SCREEN_HEIGHT, &Wire, OLED_RESET);

#define NUMFLAKES 10  // Number of snowflakes in the animation example

#define LOGO_HEIGHT 16
#define LOGO_WIDTH 16
static const unsigned char PROGMEM logo_bmp[] = { 0b00000000, 0b11000000,
                                                  0b00000001, 0b11000000,
                                                  0b00000001, 0b11000000,
                                                  0b00000011, 0b11100000,
                                                  0b11110011, 0b11100000,
                                                  0b11111110, 0b11111000,
                                                  0b01111110, 0b11111111,
                                                  0b00110011, 0b10011111,
                                                  0b00011111, 0b11111100,
                                                  0b00001101, 0b01110000,
                                                  0b00011011, 0b10100000,
                                                  0b00111111, 0b11100000,
                                                  0b00111111, 0b11110000,
                                                  0b01111100, 0b11110000,
                                                  0b01110000, 0b01110000,
                                                  0b00000000, 0b00110000 };

void setup() {
  Serial.begin(19200);  // for debug console
  printConfig();        // output basic info

  // SSD1306_SWITCHCAPVCC = generate display voltage from 3.3V internally
  if (!display.begin(SSD1306_SWITCHCAPVCC, SCREEN_ADDRESS)) {
    Serial.println(F("SSD1306 allocation failed"));
    for (;;)
      ;  // Don't proceed, loop forever
  }

  // Show initial display buffer contents on the screen --
  // the library initializes this with an Adafruit splash screen.
  display.display();
  delay(2000);  // Pause for 2 seconds

  // Clear the buffer
  Serial.println(F("Clear Display"));
  display.clearDisplay();

  // Draw a single pixel in white
  display.drawPixel(10, 10, SSD1306_WHITE);

  // Show the display buffer on the screen. You MUST call display() after
  // drawing commands to make them visible on screen!
  display.display();
  delay(2000);
  // display.display() is NOT necessary after every single drawing command,
  // unless that's what you want...rather, you can batch up a bunch of
  // drawing operations and then update the screen all at once by calling
  // display.display(). These examples demonstrate both approaches...

  testdrawline();  // Draw many lines

  testdrawrect();  // Draw rectangles (outlines)

  testfillrect();  // Draw rectangles (filled)

  testdrawcircle();  // Draw circles (outlines)

  testfillcircle();  // Draw circles (filled)

  testdrawroundrect();  // Draw rounded rectangles (outlines)

  testfillroundrect();  // Draw rounded rectangles (filled)

  testdrawtriangle();  // Draw triangles (outlines)

  testfilltriangle();  // Draw triangles (filled)

  testdrawchar();  // Draw characters of the default font

  testdrawstyles();  // Draw 'stylized' characters

  testscrolltext();  // Draw scrolling text

  testdrawbitmap();  // Draw a small bitmap image

  // Invert and restore display, pausing in-between
  display.invertDisplay(true);
  delay(1000);
  display.invertDisplay(false);
  delay(1000);

  testanimate(logo_bmp, LOGO_WIDTH, LOGO_HEIGHT);  // Animate bitmaps
}

void loop() {
}

void testdrawline() {
  Serial.println(F("testdrawline()"));
  int16_t i;

  display.clearDisplay();  // Clear display buffer

  for (i = 0; i < display.width(); i += 4) {
    display.drawLine(0, 0, i, display.height() - 1, SSD1306_WHITE);
    display.display();  // Update screen with each newly-drawn line
    delay(1);
  }
  for (i = 0; i < display.height(); i += 4) {
    display.drawLine(0, 0, display.width() - 1, i, SSD1306_WHITE);
    display.display();
    delay(1);
  }
  delay(250);

  display.clearDisplay();

  for (i = 0; i < display.width(); i += 4) {
    display.drawLine(0, display.height() - 1, i, 0, SSD1306_WHITE);
    display.display();
    delay(1);
  }
  for (i = display.height() - 1; i >= 0; i -= 4) {
    display.drawLine(0, display.height() - 1, display.width() - 1, i, SSD1306_WHITE);
    display.display();
    delay(1);
  }
  delay(250);

  display.clearDisplay();

  for (i = display.width() - 1; i >= 0; i -= 4) {
    display.drawLine(display.width() - 1, display.height() - 1, i, 0, SSD1306_WHITE);
    display.display();
    delay(1);
  }
  for (i = display.height() - 1; i >= 0; i -= 4) {
    display.drawLine(display.width() - 1, display.height() - 1, 0, i, SSD1306_WHITE);
    display.display();
    delay(1);
  }
  delay(250);

  display.clearDisplay();

  for (i = 0; i < display.height(); i += 4) {
    display.drawLine(display.width() - 1, 0, 0, i, SSD1306_WHITE);
    display.display();
    delay(1);
  }
  for (i = 0; i < display.width(); i += 4) {
    display.drawLine(display.width() - 1, 0, i, display.height() - 1, SSD1306_WHITE);
    display.display();
    delay(1);
  }

  delay(2000);  // Pause for 2 seconds
}

void testdrawrect(void) {
  Serial.println(F("testdrawrect()"));
  display.clearDisplay();

  for (int16_t i = 0; i < display.height() / 2; i += 2) {
    display.drawRect(i, i, display.width() - 2 * i, display.height() - 2 * i, SSD1306_WHITE);
    display.display();  // Update screen with each newly-drawn rectangle
    delay(1);
  }

  delay(2000);
}
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

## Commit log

2023-07-01 Initial Upload at v1.1
    For MERG Article
    [MaxDuino_Assembly_Instructions R1.1.xlsm, MaxDuino_R1.1.kicad_pcb, MaxDuino_R1.1.kicad_sch]
2023-08-19 Create MaxDuino Development Roadmap.xlsx
    Main Planning document showing proposed developments for the MaxDuino platform and timing of same.
    [MaxDuino Development Roadmap.xlsx]
2023-08-21 Update MaxDuino Development Roadmap.xlsx
    [MaxDuino Development Roadmap.xlsx]
2023-09-08 Rev 1.2
    Minor Improvements to RS485 circuit and NeoPixel circuit.
    Revisited documentation. Test code for RS485 will need updating (when I have the PCB's in hand)
    [MaxDuino Development Roadmap.xlsx, MaxDuino_R1.1.kicad_pcb, MaxDuino_R1.1.kicad_sch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]
2023-09-28 Made both R1.1 and R1.2 available
    Slight differences in what works or does not work.
    Recommended: R1.1 as all features work but only uses a single pin for RS485 direction control.
    [MaxDuino Development Roadmap.xlsx, MaxDuino_R1.1 Panelized.kicad_pcb, MaxDuino_R1.1 Panelized.kicad_sch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]
2023-10-15 Updated for R1.4 (and R1.3)
    MERG Journal article submitted was based on R1.3 (All testing passed, plus improvement suggestions from R1.1 all incorporated).
    In the editing and proofing process some PCB stencil errors were noted on the R1.3 PCB - version 1.4 fixes these minor issues.
    Electrically R1.3 and R1.4 are the same.
    [MaxDuino_R1.1 Panelized.kicad_pcb, MaxDuino_R1.2_Panel.kicad_pcb, MaxDuino_R1.4.kicad_pro.kicad_pcb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]
2023-10-15 Updated Roadmap Post R1.4
    [MaxDuino Development Roadmap.xlsx]
2023-11-30 Ver 1.5 plus Reorg files
    With V1.5 being pushed out I decided to organize files by version number. Thus all files associated with a given version are in one folder. This is cleaner and makes finding relevant files easy. Obso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
    [MaxDuino Development Roadmap.xlsx, MaxDuino_R1.1.kicad_pcb, MaxDuino_R1.1.kicad_sch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]
2023-12-21 Updated to R1.6
    Minor updates to PCB
    [MaxDuino_R1.6.kicad_pcb, MaxDuino_R1.6.kicad_sch, R1.5 MaxDuino KiCad Files.kicad_pcb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]
2024-06-15 Documentation Improvements
    Improved documentation, added photos.
    [MaxDuino_R1.6.kicad_pcb, MaxDuino_R1.6.kicad_sch]

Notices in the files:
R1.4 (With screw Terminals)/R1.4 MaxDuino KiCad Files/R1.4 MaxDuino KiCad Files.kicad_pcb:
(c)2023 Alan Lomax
